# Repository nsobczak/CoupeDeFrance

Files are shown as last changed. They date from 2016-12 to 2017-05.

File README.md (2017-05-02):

# Coupe de France de robotique

## Robot principal

Notre robot principal doit être capable de réaliser les modules suivants :

| Nom du module | Priorité |
|---|---|
|Ramassage de cylindres |Moyenne|
|Funny action |Haute|

## Robot secondaire

Nous n'avons pas de robot secondaire. Si nous en avions un, il se chargerait du module suivant :

| Nom du module | Priorité |
|---|---|
|Ramassage de boules |Basse|

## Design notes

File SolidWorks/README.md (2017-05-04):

# SolidWorks

Pour ouvrir les assemblages :

-> Pour le mécanisme avec la pince :
El padre\isen2016-2017\SUPPORT DU MILIEU.SLDASM
-> Pour les mécanismes sur le robot :
El padre\Base roulante\Base du robot\Base_grand_robot_V3.SLDASM
-> Pour la funny action :
El padre\ Pince \ assemblage canon.SLDASM

Nb : Tous les éléments sont à l'echelle y compris le robot. Le robot a été agrandi pour la coupe de
	france de 2017 grace à des plaques visibles et équerres de fixation.
		Si vous avez des questions sur l'assemblage posez les à : olivier.jombart@isen.yncrea.fr
			Désolé pour le nommage de certaines pièces....

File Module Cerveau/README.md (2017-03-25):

# Module cerveau

Il s'agit du dossier contenant tout ce qui concerne le cerveau du robot : écran, software, harware...
Ce dossier contient aussi les dossiers communs à tous les modules, comme l'i2c par exemple.

## Dossiers propres au cerveau

- "Artificial Intelligence" est le dossier dans lequel est conservé ce qui concerne l'intelligence artificielle du robot.
- "Ecran" est le dossier dans lequel est conservé ce qui concerne l'écran.
- "ShieldCerveau" est le dossier contenant le harware du shield de la carte du cerveau.

## Dossiers communs aux différents modules

- "I2C" est le dossier contenant notre bibliothèque i2c et tests.

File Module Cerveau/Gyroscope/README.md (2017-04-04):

# Gyroscope/Accelerometre

Ce dossier contient les codes de tests de notre Gyroscope/Accelerometre.

Des information sur son utilisation peuvent être trouvée ici : https://knowledge.parcours-performance.com/ajouter-gyroscope-a-robot-arduino/

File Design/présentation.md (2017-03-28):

# notes

- chatterton
- plaque de plexi
- barre de led + fixation (4*7cm)
- adobe indesign

vendredi 31/03 : 11h-15h

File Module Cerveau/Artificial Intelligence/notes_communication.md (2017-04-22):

# Notes de communication

## 1. Notes I2C

- envois sur adresse paire
- réceptions sur adresse impaire

### Capteurs

I2C de la carte capteur => carte mère  (adresse 11):
- envoi des valeurs des capteurs ir et us (5 + 4 = 9 fois (10 s'ils fonctionnent tous))

### Gyroscope

Gyro => carte mère (adresse 68/69):
- envoi angle pour le connaître en temps réel (1 donnée: angle selon z)

### Carte mère

carte mère => carte asservissement (adresse 6):
- envoi angle pour stopper rotation quand angle est bien
- envoi ordre de déplacement du robot avec distance et vitesse: 1er octet correspond à l'ordre, 2ème à la partie entière de la consigne de distance, 3ème à la partie entière de la consigne de distance, 4ème à la partie entière de la consigne de vitesse, 5ème octet correspond à la partie décimale

carte mère => pince (adresse 8):
- envoi ordre à déclencher (y'en a 3)

## 2. Notes SPI

### Ecran

ecran => carte mère (adresse 13 ):
- envoi de la stratégie
- envoi de la couleur

## 3. Autre

### funny action

funny action :
- carte mère envoie un état haut à la nano qui commence à compter 90" et déclenche la funny action à la fin

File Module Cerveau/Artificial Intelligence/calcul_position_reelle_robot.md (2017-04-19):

# Calcul de la position réelle du robot

Le calcul de la position réelle est à réaliser en même temps que celui de l'asservissement en vitesse.

## Données

Nous disposons des données suivantes :

- ticks des codeuses
- distance séparant les 2 codeuses: voie
- nombre de ticks par tour de roue
- périmètre d'une roue codeuse

A partir du nombre de ticks, on calcule la distance réelle parcourue par le robot.

On place l'origine de l'axe x,y en bas à gauche du plateau. On place le plateau comme dans l'image ci-après, avec la zone de départ bleue placée en haut à gauche.<br>
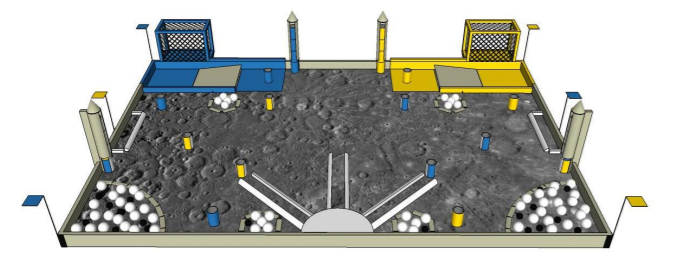
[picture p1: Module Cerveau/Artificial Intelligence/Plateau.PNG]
Plateau
<br>
L'axe y est dirigé vers la zone de départ bleue. L'axe x est dirigé vers le coin cratère de minerai jaune.

## Equations

Donnée                           | Nom de la variable
-------------------------------- | ------------------
Angle effectué en radian         | a
Distance parcourue               | d
Distance parcourue selon l'axe x | x
Distance parcourue selon l'axe y | y

- d = (ticks/nombre_ticks_par_tour_de_roue)\*perimetre_roue_codeuse
- en cas de rotation, a = voie/d
- x = d*cos(a)
- y = d*sin(a)

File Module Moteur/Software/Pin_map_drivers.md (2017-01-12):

# Pin Map Shield Moteur

# Drivermoteur gauche :
pwm - 6
IN1 - 52
IN2 - 53

# Drivermoteur Droit :
pwm - 3
IN1 - 22
IN2 - 23

# Encoder Gauche :
pinA - 13
pinB - 12

# Encoder Droit : 
pinA - 11
pinB - 10

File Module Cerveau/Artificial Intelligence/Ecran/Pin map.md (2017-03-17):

# Pin map de l'écran de controle

Les numéros correspondent aux pins de l'arduino mega.

## EXP1
----------------
|  |51|13|  |GND|  2 digital pin ,14 digital pin , 51 MOSI pin, 13 digital pin 
---------------- 
|02|14|  |  |5V|
----------------
      ----

## EXP2
----------------
|  |52|50|  |  |
----------------
|  |  |  |  |  |
----------------
      ----

----------------
|  |  |  |  |  |
----------------
|  |  |  |  |  |
----------------
      ----

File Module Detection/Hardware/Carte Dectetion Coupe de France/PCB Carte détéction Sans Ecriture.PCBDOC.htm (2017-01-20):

Reporting Options

# File in Previous Format

Date | : | 20/01/2017
Time | : | 09:35:36
Filename | : | C:\Users\ISEN\Documents\CoupeDeFrance\Module Dectetion\Hardware\Carte Dectetion Coupe de France\PCB Carte détéction Sans Ecriture.PCBDOC

Version | Warning

This file was generated by an earlier version of the software

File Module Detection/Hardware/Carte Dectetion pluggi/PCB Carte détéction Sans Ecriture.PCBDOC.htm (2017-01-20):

Reporting Options

# File in Previous Format

Date | : | 20/01/2017
Time | : | 09:43:30
Filename | : | C:\Users\ISEN\Documents\CoupeDeFrance\Module Dectetion\Hardware\Carte Dectetion pluggi\PCB Carte détéction Sans Ecriture.PCBDOC

Version | Warning

This file was generated by an earlier version of the software

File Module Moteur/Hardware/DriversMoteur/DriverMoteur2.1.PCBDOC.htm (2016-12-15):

Reporting Options

# File in Previous Format

Date | : | 09/12/2016
Time | : | 20:24:48
Filename | : | C:\Users\ISEN\Desktop\Projet coupe de France\Driver2.1\DriverMoteur2.1.PCBDOC

Version | Warning

This file was generated by an earlier version of the software

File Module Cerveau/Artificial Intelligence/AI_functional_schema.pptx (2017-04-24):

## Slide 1

Sens de lecture

El padre IA
Si tirette tirée

Fin du timer ?

Cylindre devant ?

Bouton d'arrêt d'urgence enclenché ?

Cylindre tenu ?

Adversaire présent ?

Aller vers la position théorique d'un cylindre de la liste

Cylindre tenu ?

Lâcher cynlindre

Dépôt de cylindre présent ?

Adversaire présent ?

Aller au dépôt

stopAll +
delay forever

Stop pendant un certain temps

Légende :

Condition

Action

Rammasser cylindre

Lâcher cylindre

Stop pendant un certain temps

Stop

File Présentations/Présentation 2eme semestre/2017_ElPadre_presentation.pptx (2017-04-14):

## El Padre

El Padre

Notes: Commentaire

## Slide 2

1.Intro

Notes: Commentaire

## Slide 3

1.1-Contexte

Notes: Commentaire

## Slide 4

1.2-Objectif

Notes: Commentaire

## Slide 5

1.3-Présentation équipe

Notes: Commentaire

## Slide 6

2.Présentation résultats

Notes: Commentaire

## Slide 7

3.Organisation

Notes: Commentaire

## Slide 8

4.Partie technique

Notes: Commentaire

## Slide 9

4.1-Intelligence artificielle

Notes: Commentaire

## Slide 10

4.1.1-Ecran

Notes: Commentaire

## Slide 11

4.1.2-Communication I2C/SPI

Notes: Commentaire

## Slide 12

4.1.3-Gyroscope

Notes: Commentaire

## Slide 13

4.1.4-Capteurs

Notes: Commentaire

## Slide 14

4.2-Asservissement

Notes: Commentaire

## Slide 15

4.2.1-Asservissement position

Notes: Commentaire

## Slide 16

4.2.2-Asservissement vitesse

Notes: Commentaire

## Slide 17

4.2.3-Drivers moteurs

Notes: Commentaire

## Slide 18

4.3-Pince

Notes: Commentaire

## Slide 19

4.3.1-Mécanique

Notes: Commentaire

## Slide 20

4.3.2-Software

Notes: Commentaire

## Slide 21

4.3.3-Hardware

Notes: Commentaire

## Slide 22

4.4-Funny action

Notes: Commentaire

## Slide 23

4.4.1-Mécanique

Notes: Commentaire

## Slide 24

4.4.2-Hardware

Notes: Commentaire

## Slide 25

4.4.3-Software

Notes: Commentaire

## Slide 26

5.Conclusion

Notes: Commentaire

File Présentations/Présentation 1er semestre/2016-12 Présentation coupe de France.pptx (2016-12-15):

## Coupe de France de robotique

Coupe de France de robotique

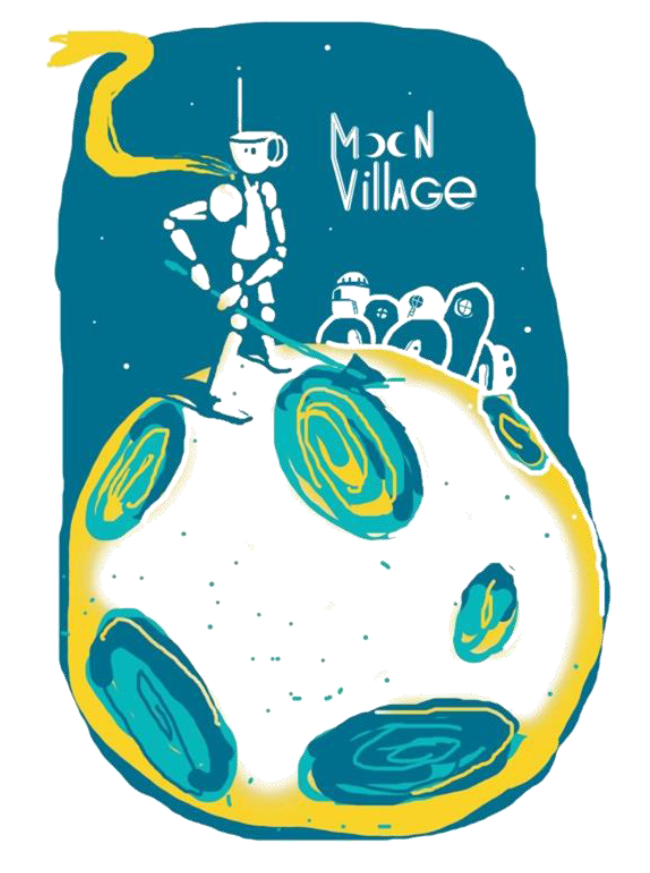
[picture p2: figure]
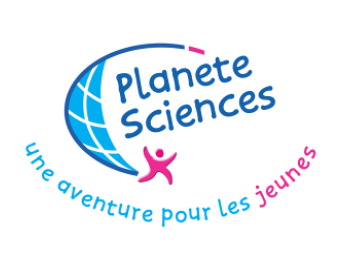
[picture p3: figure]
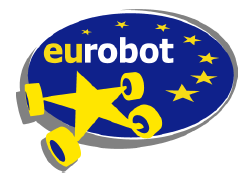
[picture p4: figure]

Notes: Commentaire

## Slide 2

Intro présentation de la coupe de France

Balles
Cylindres
Funny action
2 points par balle apportée dans la zone de départ
3 points par balle apportée dans le panier
10 points par cylindre apporté dans un rail
20 points si réalisée correctement
2 points par cylindre apporté dans la zone de départ

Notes: Commentaire

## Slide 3

Aire de jeu

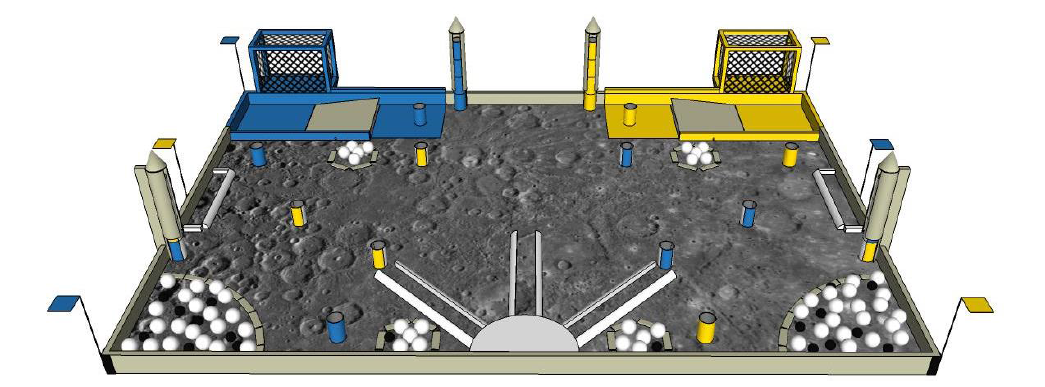
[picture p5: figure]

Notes: Commentaire

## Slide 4

Objectif du 1er semestre

Objectif du 1er semestre : faire rouler le robot

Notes: Commentaire

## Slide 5

Plan

I. Architecture du robot
II. L’écran
III. Les moteurs
IV. L’alimentation
V. Documentation

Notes: Commentaire

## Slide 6

I. L’architecture du robot

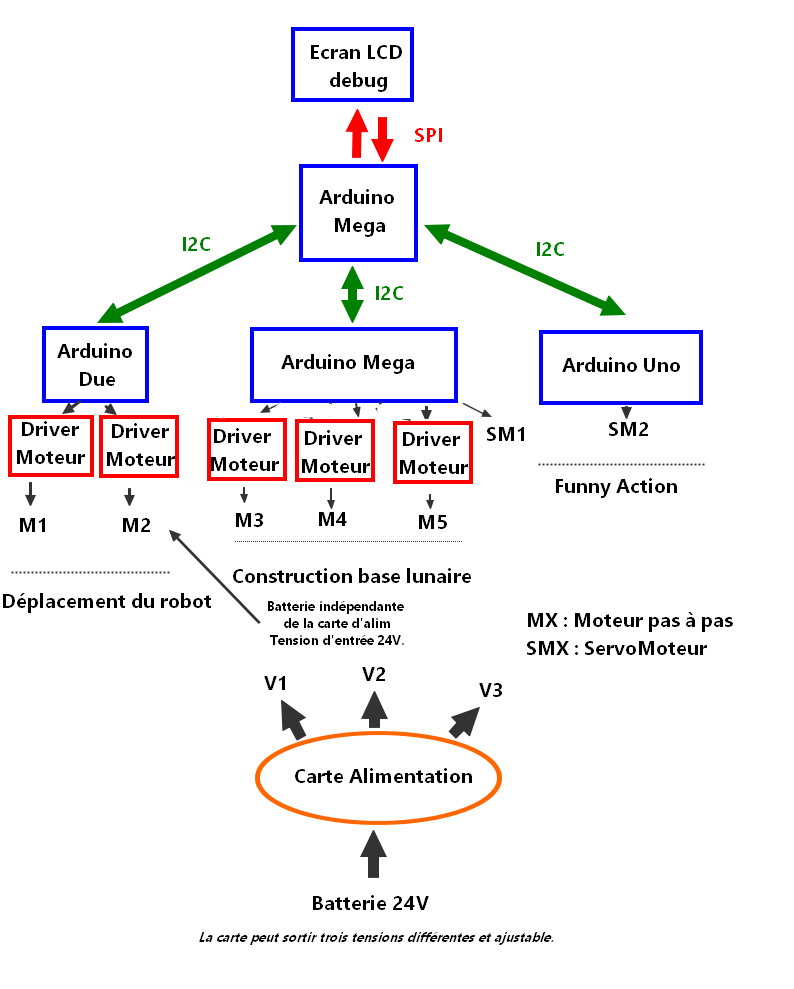
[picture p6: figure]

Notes: Commentaire

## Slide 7

II.1 L’écran

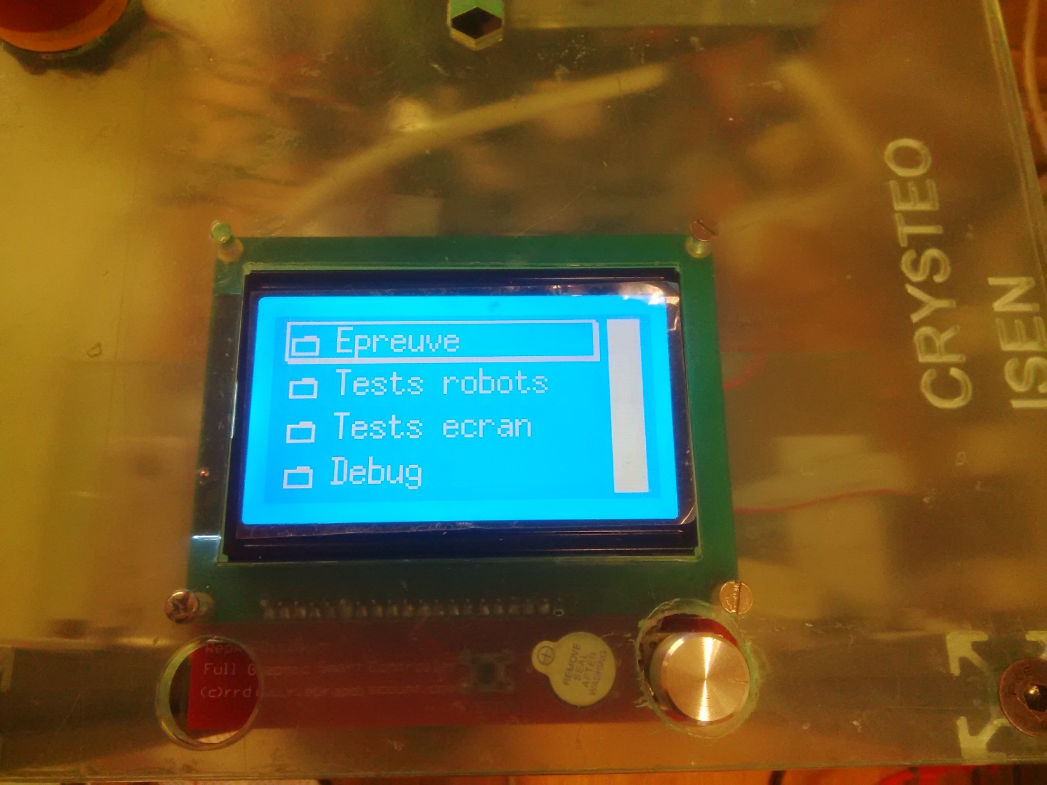
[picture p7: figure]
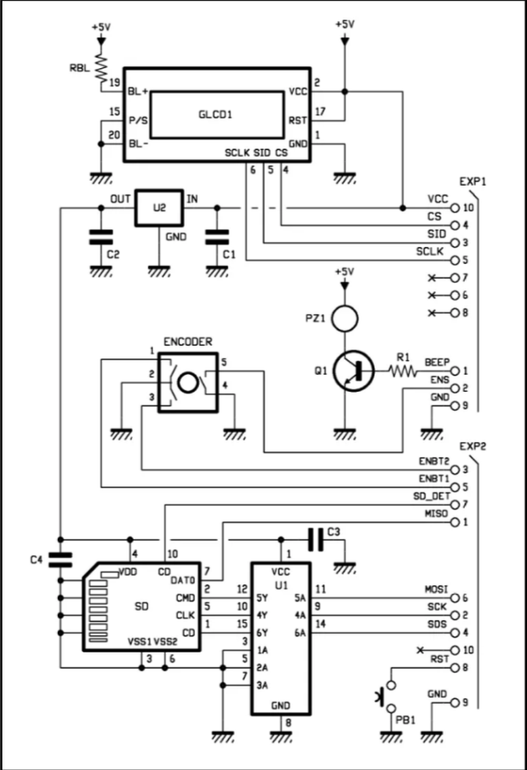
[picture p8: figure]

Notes: Ecran led - Encodeur qui a un bouton - Carte sd si besoin - Bouton poussoir
Intérêt = minimiser le nombre de boutons, choix de la stratégie, debug

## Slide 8

II.2 Les menus de l’écran actuel

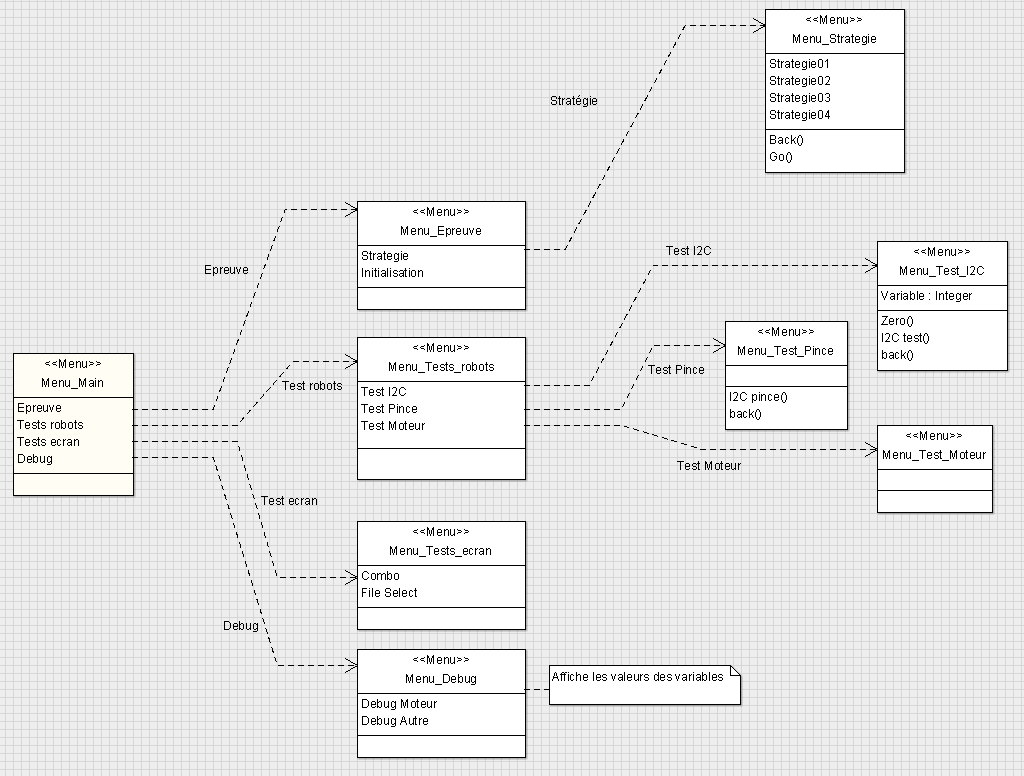
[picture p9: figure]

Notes: Gérer par une arduino mega. L’arduino mega = 7V. Ecran = 5V.
Communication entre les 2 = SPI
Programmation = biblio pour gérer l’écran et une pour gérer les menus
Démonstration de l’écran après si vous voulez

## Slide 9

III. Les moteurs

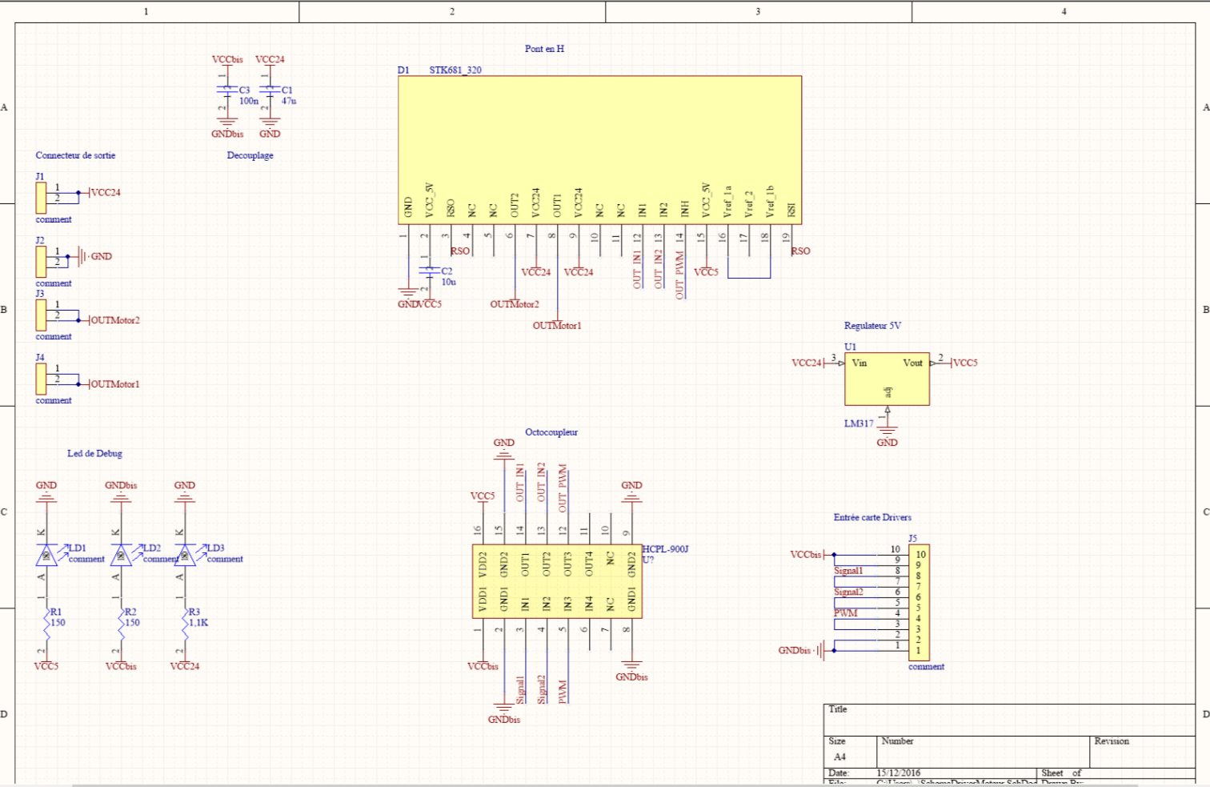
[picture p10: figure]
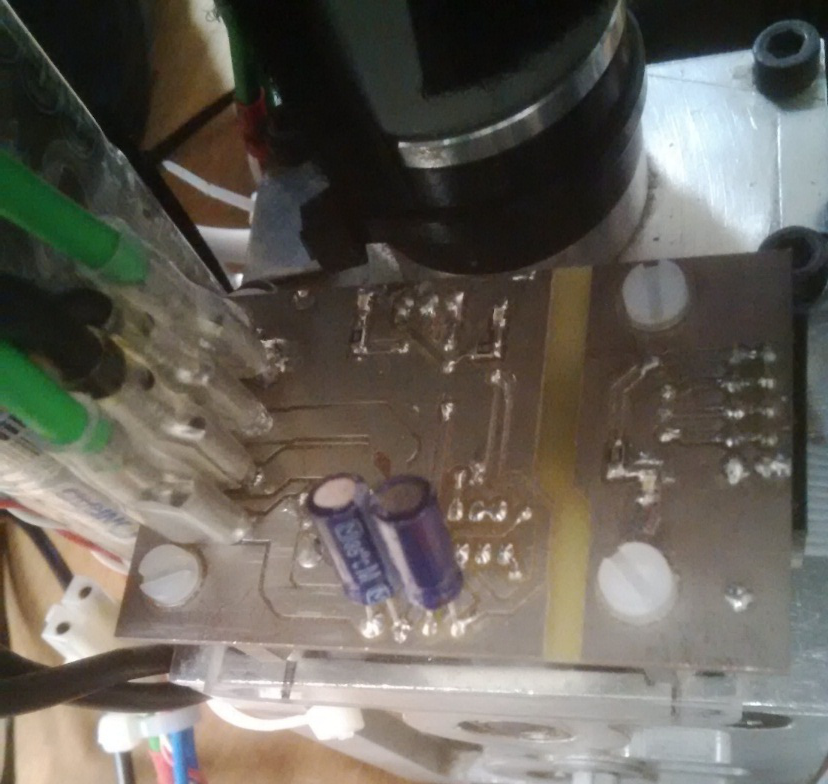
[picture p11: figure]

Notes: Commentaire

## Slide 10

IV. L’alimentation

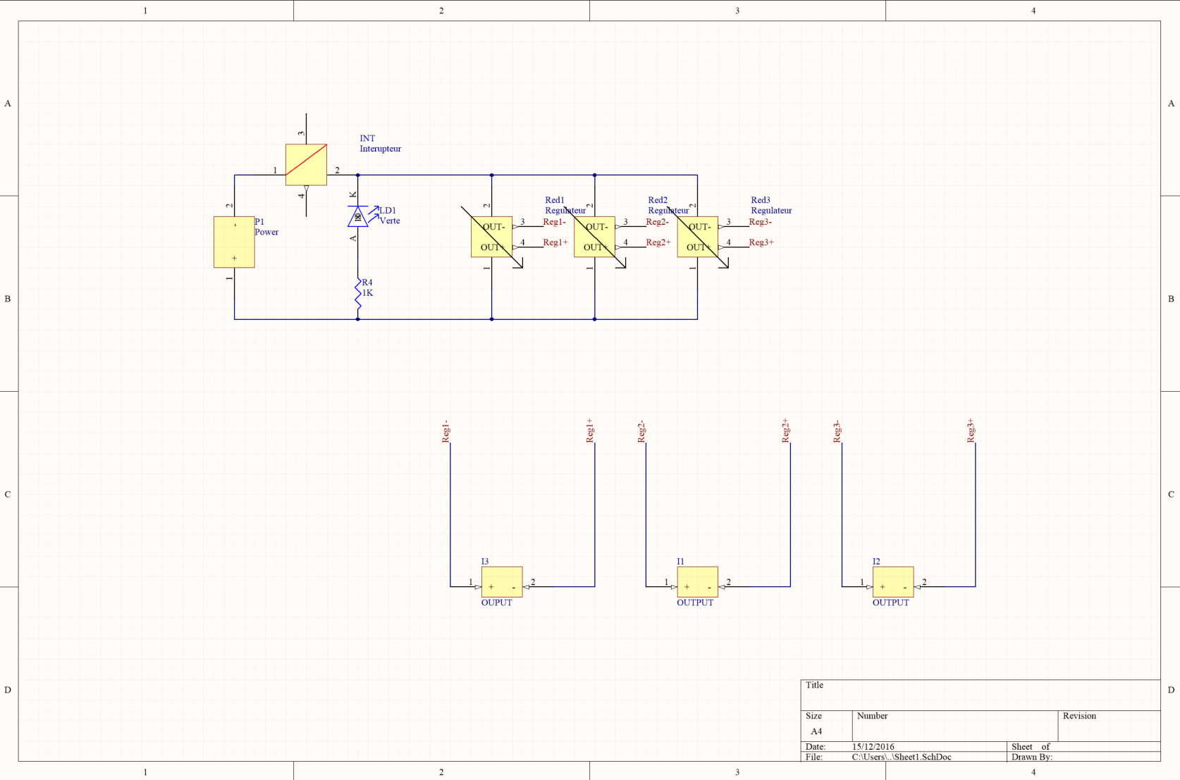
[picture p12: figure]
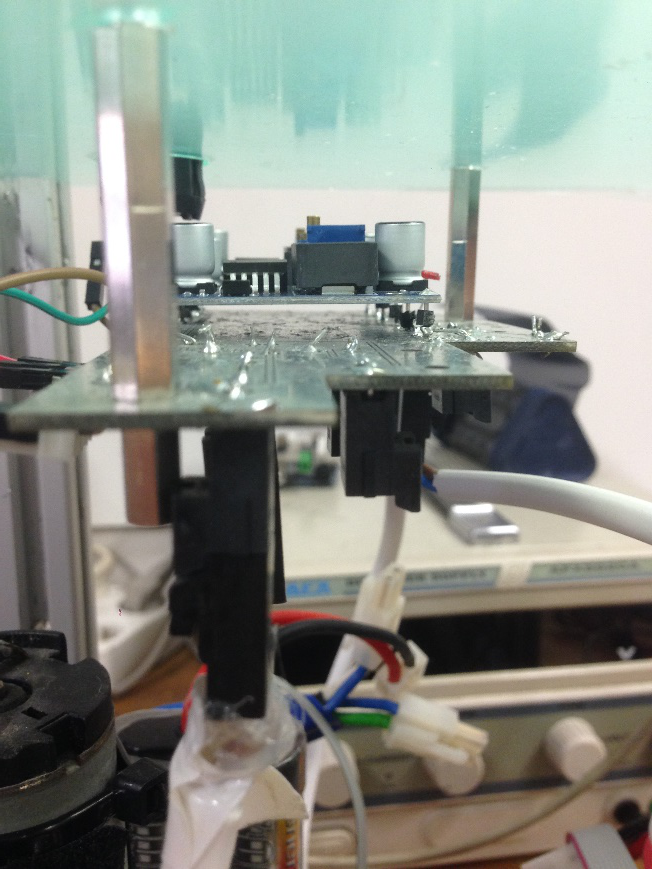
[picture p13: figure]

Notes: - Régulateur de tension basé sur principe d’alim à découpage

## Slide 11

V. Documentation

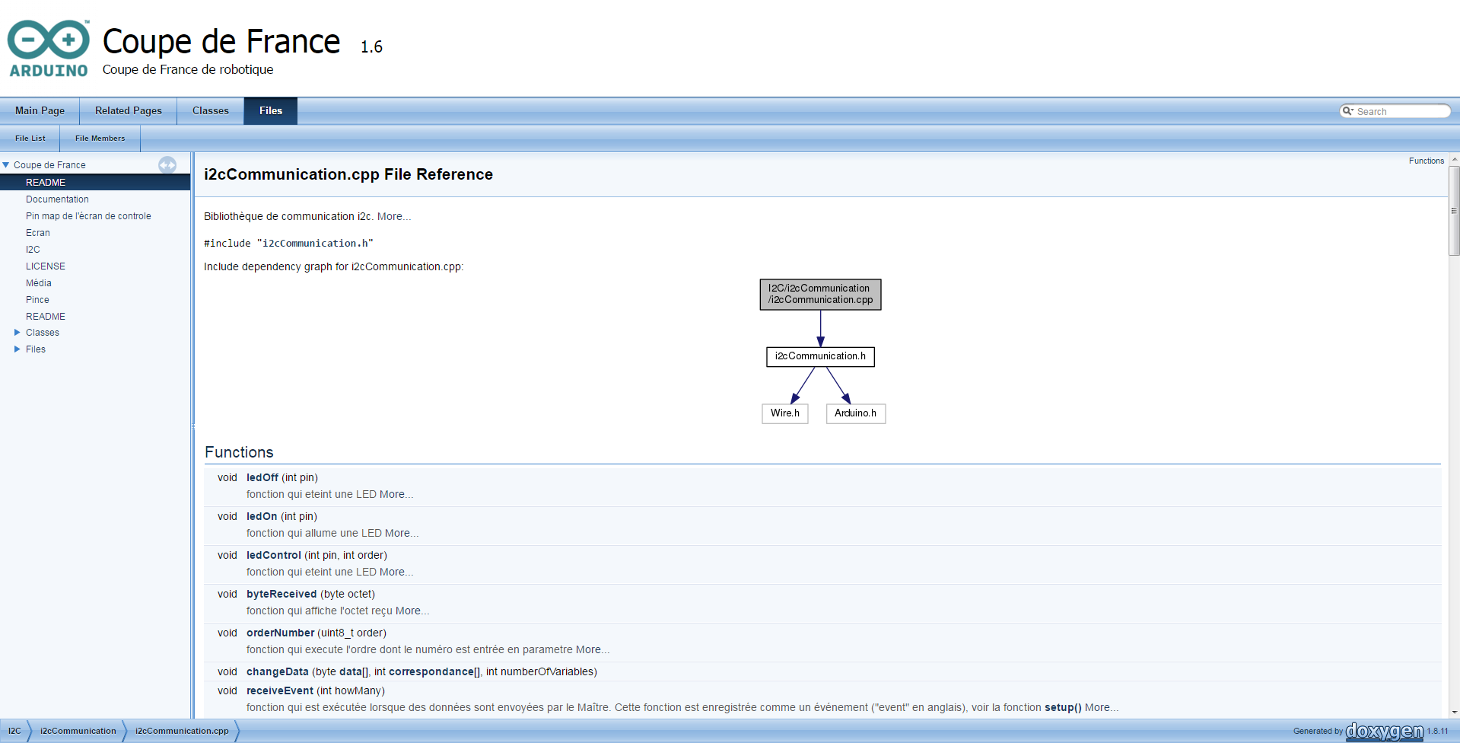
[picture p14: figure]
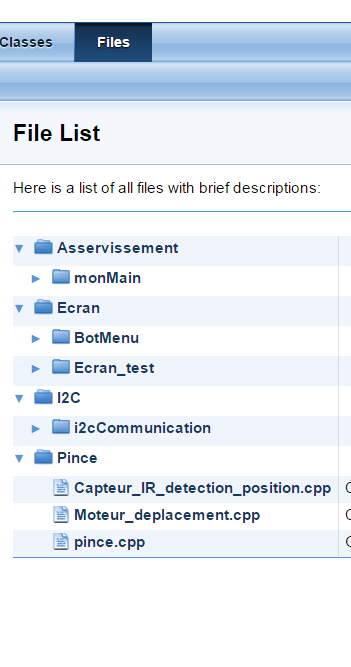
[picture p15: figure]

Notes: - Robot le plus réutilisable possible
- Mise en place de documentation => on commente le code (Doxygen), schéma élctrique, pin map…
- On utilise github pour sauvegarder tous nos fichiers => vous pouvez aller voir
- Au début on est parti sur des choses simples => maintenant on utilise les tag de c++ pour générer documentation

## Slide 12

V. Documentation

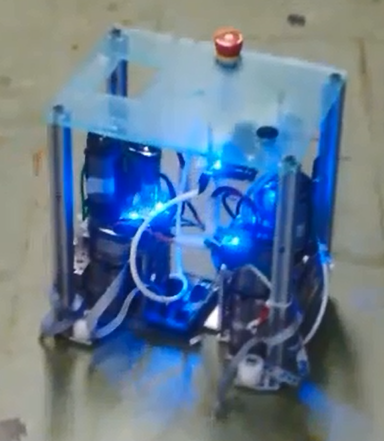
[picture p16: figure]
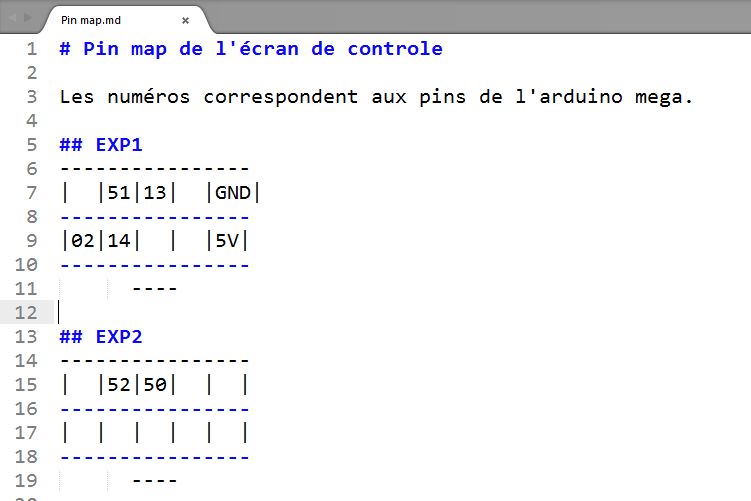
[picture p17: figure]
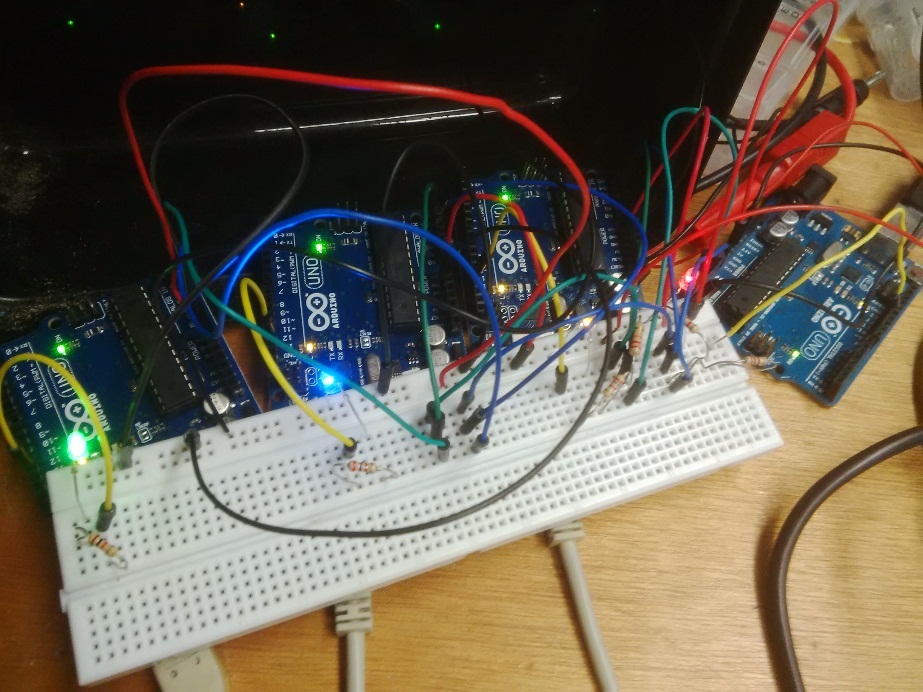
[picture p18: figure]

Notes: - Mise en place d’automatisme de documentation
- Prise de photos et vidéos

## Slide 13

Démonstration

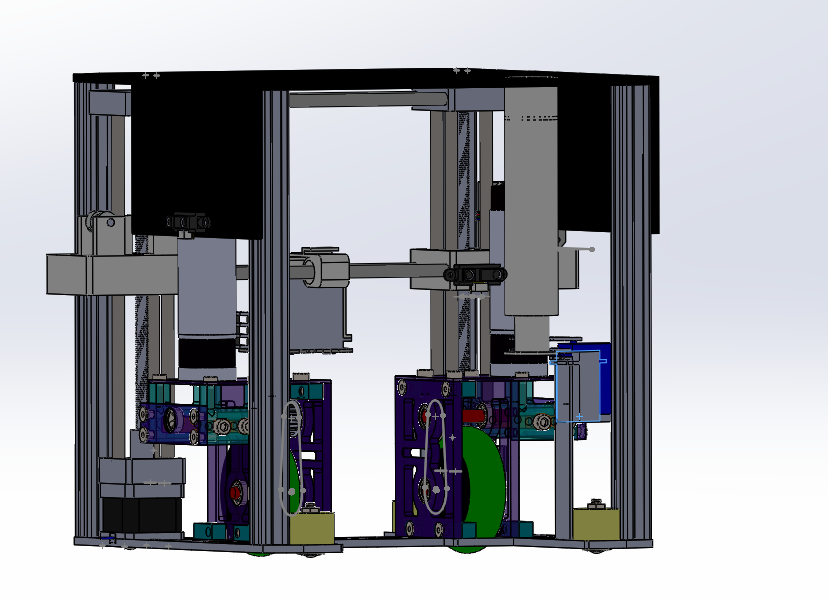
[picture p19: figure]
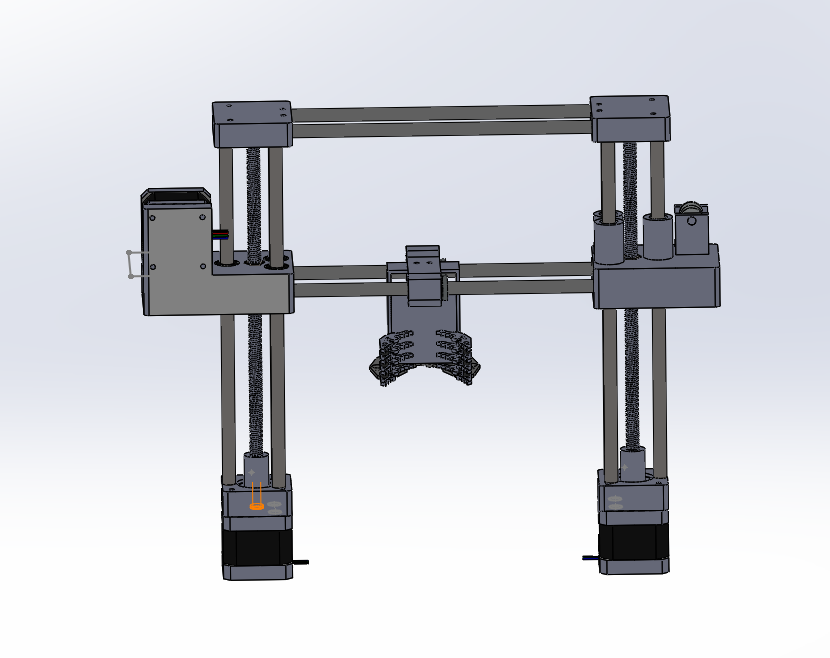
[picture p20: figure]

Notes: Commentaire

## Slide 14

Conclusion

Notre objectif est rempli
Il nous reste encore la partie actionneur à faire
Il nous faudrait plus de monde

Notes: Commentaire

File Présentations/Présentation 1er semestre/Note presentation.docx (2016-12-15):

Arthur
Nicolas
Olivier

# Intro

Expliquer coupe France + épreuves + point

Mentionner nos objectifs pour 1 semestre + objectif final

# 1. Expliquer l’architecture du robot

1 microcontrôleur par module -> Car si un crash les autres ne sont pas impactées

Donc 3 microcontrôleur pour chaque épreuve.

Plus 1 microcontrôleur pour gère le tout (faire le cerveau)

Plus 1 microcontrôleur pour gérer les moteurs (déplacement du robot)

Communication en I2C création de notre propre bibliothèque

# 2. Module Ecran

Ecran LED + encoder (possibilité d’utilisation d’une carte SD + bouton poussoir)

Intérêt : Debug, Choix stratégie, enlever tous les boutons

Gérer par la carte maître alimentée (Arduino Méga)

Tension d’alimentation : 7V Arduino Méga 5V Ecran

Communication : Ecran Arduino SPI

Programmation : utilisation bibliothèques

# 3. Moteur

Moteur 24V 2 A

Schéma électrique

Entrée : 3 signaux logique (IN1 IN2 PWM) 3.3V

Sortie : PWM 24V 1 à 2 A

Optocoupleur : isolation des masses et des signaux

Pont en H : Gere la puissance et le sens du moteur se met en sécurité à partir de 8A (réglable)

Régulateur 5V : fournie niveaux logiques au pont en H et alimente optocoupleur

Finie et opérationnel !!

Arduino Due fonctionnement 89 Mhz -> Car fréquence d’envoie des ticks importante

Alimentation 7V

Gere l’asservissement niveau documentation

# 4. Alimentation

Carte primordiale du robot-> opérationnel rapidement

Carte d’alimentation provisoire sortie 3 tension réglable 1 A Max tension d’entrée 24V

7V->Arduino, 5V-> Driver Moteur, Ecran 12V-> Moteur pas à pas

Amélioration au second semestre 5A Max 3 tension sortie amélioration

Capa découplage, Largeur des piste, connecteur, éventuellement fusible

# 5. Documentation

Robot le plus réutilisable possible

Mise en place d’automatisme de documentation

Prise de photo et vidéo, code commenter

Mise en place d’outil de partage et documentation

GitHub :

Partie hardware Partie software

(107 sauvegarde)

Documentation automatique

DOXYGEN v1.8.11

Nous sommes actuellement à la version v1.6 de la documentation

# Conclusion

- Dire objectif rempli + ce qu’on compte faire + finir sur les ressources

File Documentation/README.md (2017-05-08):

# Documentation

Ce dossier est destiné à acceuillir tout ce qui concerne la documentation.
Pour visualiser la documentation, il faut lancer le fichier html/index.html

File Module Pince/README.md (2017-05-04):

## Moteur_deplacement

Dossier contenant le fichier du code pour lancer les moteurs de déplacement de la pince.

## Tests

Dossier de tests.
---Inutile---

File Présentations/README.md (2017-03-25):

# Présentation

Dossier contenant les différentes présentations.

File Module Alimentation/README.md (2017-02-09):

# Module Alimentation

Il s'agit du dossier contenant le hardware de la carte d'alimentation.

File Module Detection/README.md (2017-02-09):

# Module Détection

Dossier contenant le hardware et le software du module de détection.

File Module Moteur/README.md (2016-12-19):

# Module moteur

Il s'agit du dossier destiné à accueillir tout ce qui concerne la carte les moteurs servant à faire rouler le robot.

## Description des dossiers

Ce dossier est composé de 2 sous-dossiers :

- Hardware : dossier contenant toute la partie hardware des moteurs, comme la carte driver par exemple.
- Software : dossier contenant toute la partie sorftware des moteurs, comme l'asservissement par exemple.

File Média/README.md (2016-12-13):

# Média

Dossier contenant les vidéos et photos de notre projet.

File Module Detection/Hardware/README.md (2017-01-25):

# Hardware

## Carte détection coupe de France

Carte de détection du robot de la coupe de France.

## Carte détection pluggi

Carte depuis laquelle nous partons pour réaliser la carte de détection du robot de la coupe de France.

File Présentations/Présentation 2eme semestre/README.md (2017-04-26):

# Présentation 2eme semestre

Dossier contenant les fichiers ayant servi pour notre présentation du 2eme semestre.

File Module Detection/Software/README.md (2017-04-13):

# Software

## CoupeDeFranceDetectionv2.0

Code de la carte de détection du robot de la coupe de France.

## MainDetectionPluggi

Code de la carte depuis laquelle nous partons pour réaliser la carte de détection du robot de la coupe de France.

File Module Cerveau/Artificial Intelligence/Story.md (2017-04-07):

# Bot AI Story

## TODO

### Généralités

- aller ramasser et placer les cylindres
- éventuellement s'occuper du ramassage de balles
- funny action
- utiliser un timer pour vérifier si l'épreuve est finie ou pas

### Notes techniques

- faire une classe Bot qui aura toutes les fonctions du robot
- penser à prévoir des manoeuvres/actions spéciales en cas de bug (robot coincé dans un coin par exemple)
- prévoir la liste des positions théoriques des cylindres
- prévoir la liste des positions théoriques des emplacements où placer les cylindres

## 1\. Départ

On sélectionne le programme avec l'écran puis on tire la tirette.

- si on détecte que la tirette est tirée => on lance le programme
- le programme écrit un état haut dans la nano qui déclenche le timer de la funny action (à la fin des 90", on lance la funny action)
- le programme lance un timer + déplacement vers un cylindre

## 2\. Déplacement (cylindres + boules)

On se déplace vers une position théorique du cylindre.

- si c'est la fin des 90" - le temps de lâcher un cylindre,

  - si on a un cylindre, on le lâche
  - dans tous les cas, on s'arrête

- sinon

  - on corrige avec l'asservissement
  - si on détecte l'adversaire => manoeuvre d'évitement
  - si on détecte un cylindre => on le ramasse

### 2.1 Eviter l'adversaire

**TODO:** Il faut décider de quelle manière on va réagir :

- on l'attaque en lui tirant dessus ou en faisant la toupies à fond par exemple
- on s'arrête en espérant qu'il finisse par bouger
- on s'arrête pendant un certain temps, puis on repars s'il n'est plus là (sinon on recommence l'action de s'arrêter)
- on l'évite en reculant ou partant n'importe où
- on regarde ce qu'il fait, où il va et on part de l'autre côté (ça peut être difficile, faut réussir à analyser où il va)

### 2.2 Détection cylindre

**NOTE:** On ne détecte que les cylindres qui sont debouts.

**TODO:** faire une liste des positions théoriques des cylindre que l'on cherche à ramasser.

- si on est proche de la position théorique d'un cylindre, on cherche un cylindre avec les capteurs pendant une certaine durée (**TODO: à déterminer**) et si capteur renvoie l'info de présence d'un cylindre => on a trouvé un cylindre \o/

  - on se déplace pour l'attraper
  - on lance une fonction du module pince : attraper + monter + tourner
  - on se déplace pour aller le placer à une position théorique
  - une fois qu'on est arrivé, on lance une fonction du module pince : (tourner) + descendre + lâcher
  - on va à une autre position théorique de cylindre

- sinon (si on dépasse la période et qu'on a pas détecté de cylindre), on va ramasser le cylindre suivant de la liste.

### 2.3 Détection minerai

**TODO:** Cherche-t-on à ramasser les minerais ?

## 3\. Funny action

- à la fin des 90", l'arduino nano lance la funny action avec une fonction

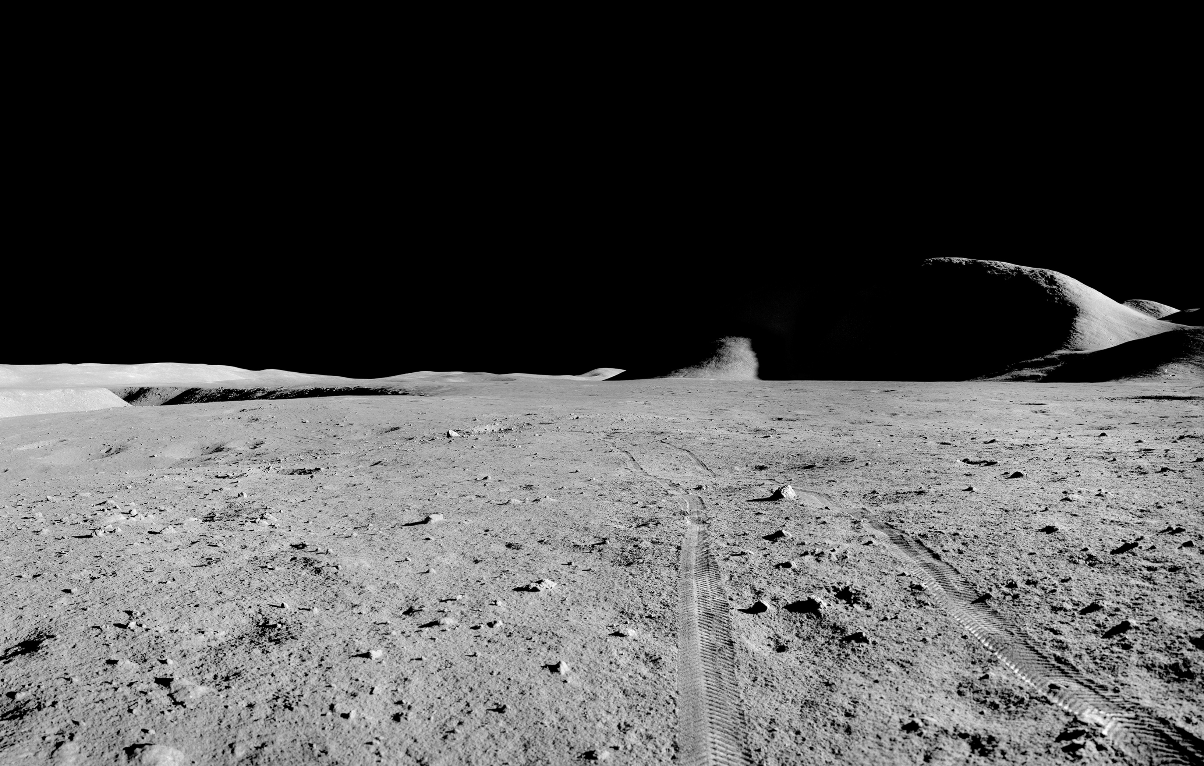
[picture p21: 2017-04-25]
Présentations/Présentation 2eme semestre/Poster/BACKGROUND.jpg

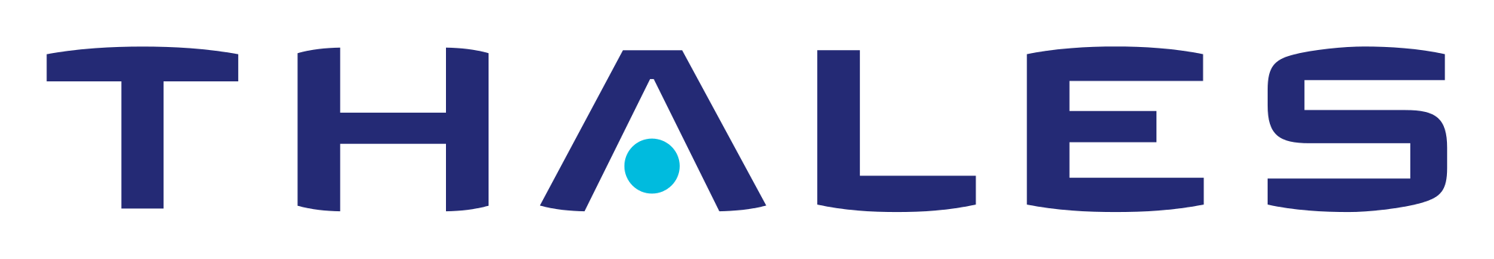
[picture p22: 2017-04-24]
Présentations/Présentation 2eme semestre/Poster/THALES.png

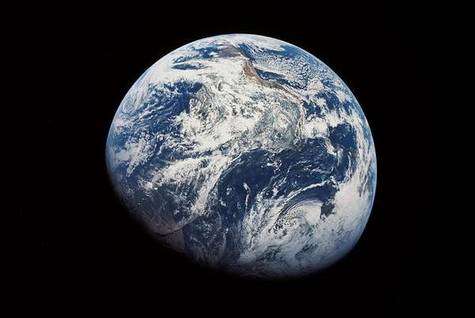
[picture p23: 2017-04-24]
Présentations/Présentation 2eme semestre/Poster/86aa8a48f0_50034785_terre-060307.jpg

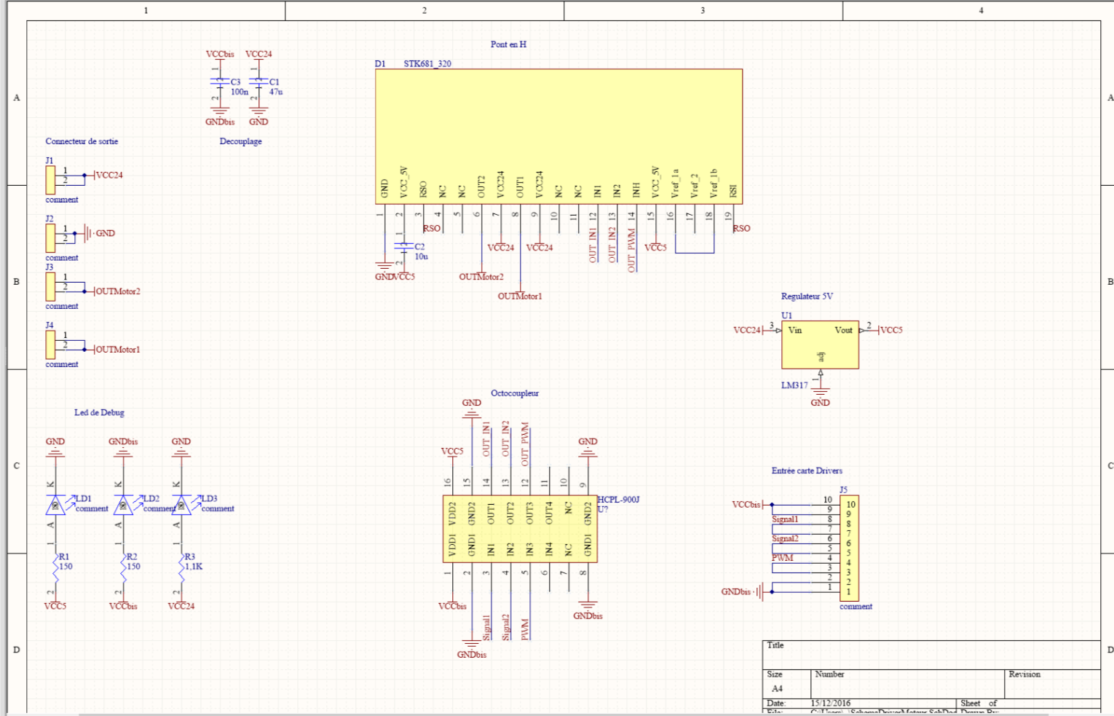
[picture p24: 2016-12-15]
Module Moteur/Hardware/DriversMoteur/Shematics.png

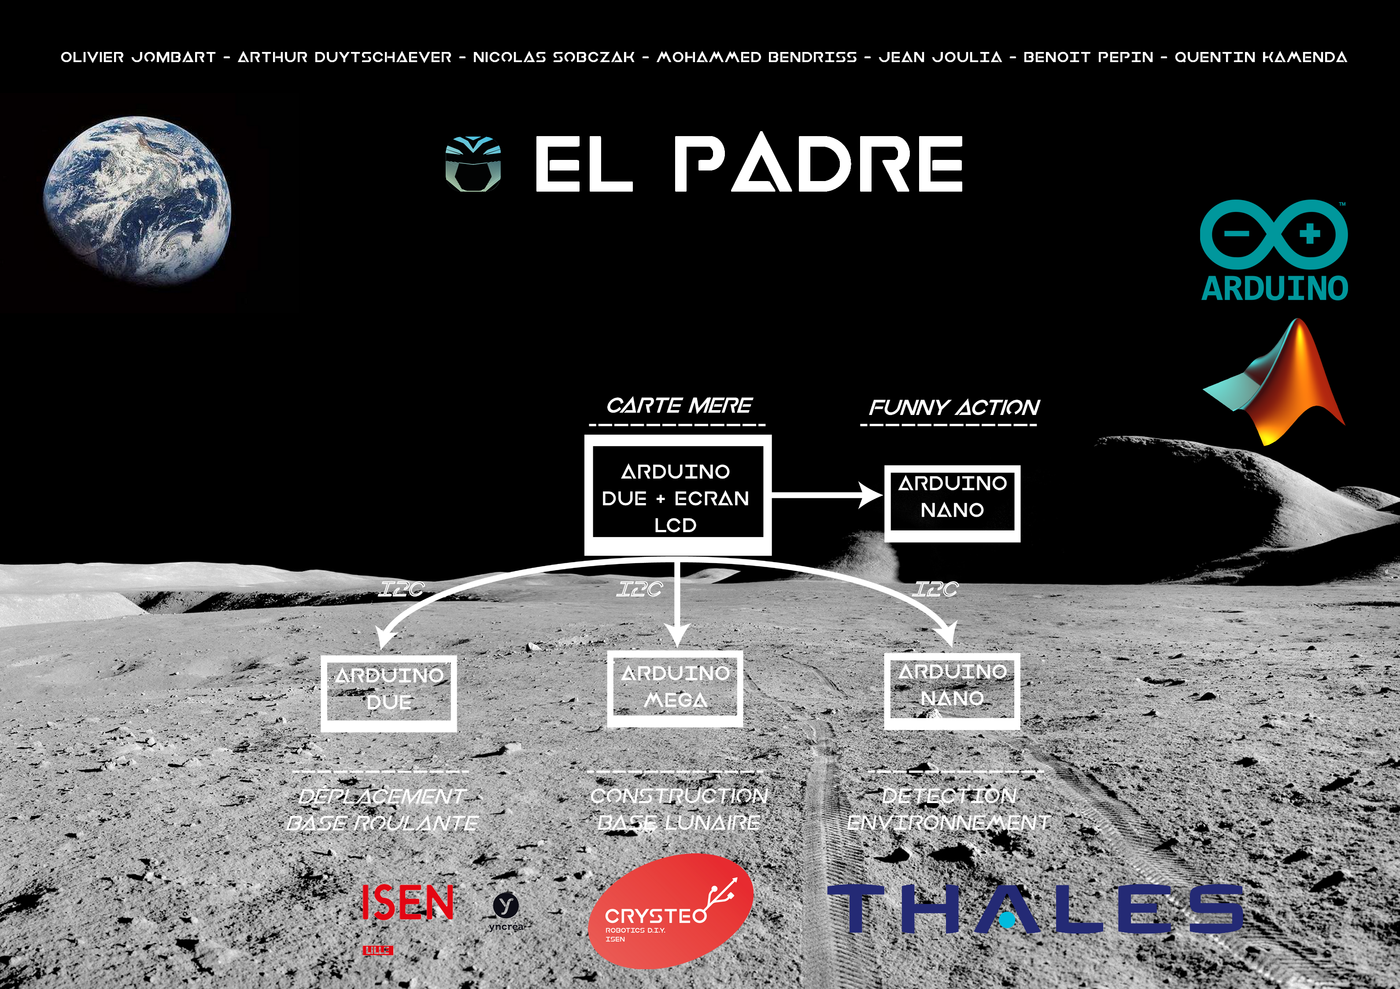
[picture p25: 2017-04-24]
Présentations/Présentation 2eme semestre/Poster/poster.png

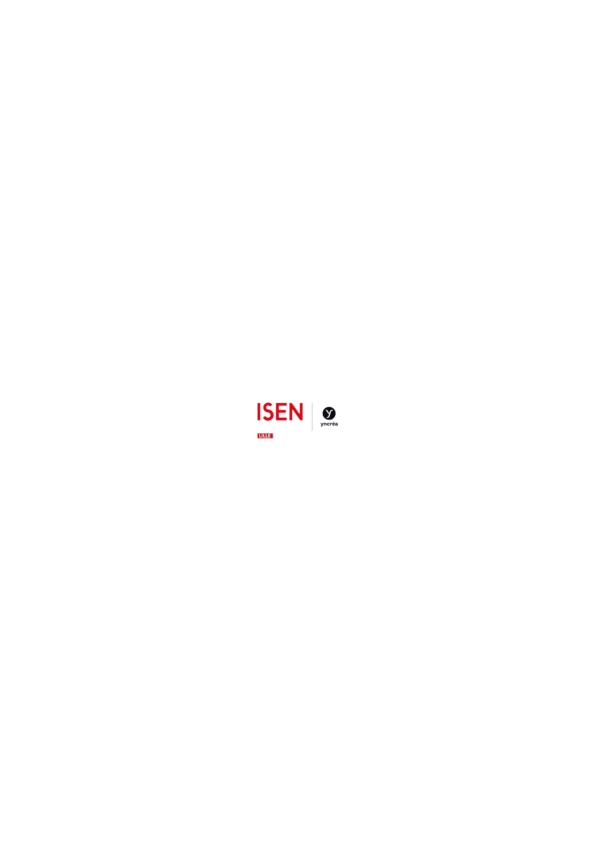
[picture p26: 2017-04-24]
Présentations/Présentation 2eme semestre/Poster/isen.png

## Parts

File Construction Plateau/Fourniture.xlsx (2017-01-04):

Caractéristique | Qté | Matériau | Prix UT | Prix Total* | Site vendeur**
Minerais (Shpère) 60mm (x60) | 3 | POLY | 6.50 € | 19.50 € | http://www.ebay.fr/itm/Lot-de-20-boules-polystyrene-Styropor-diam-6-cm-60mm-/131948207222
Roches Lunaires (Sphère) 40mm (x18) | 1 | POLY | 4.20 € | 4.20 € | https://www.stoklasa.fr/boule-en-polystyrene-37-40-mm-x127487?gclid=CJj9gvGrss8CFQVuGwody4QGfg
Champlat médium (MDF) 2 arrondis imitation chêne, 4 x 30 mm, L.2.4 m | 2 | MDF | 4.70 € | 9.40 € | http://www.leroymerlin.fr/v3/p/produits/champlat-medium-mdf-2-arrondis-imitation-chene-4-x-30-mm-l-2-4-m-e57428
Tube d'évacuation PVC, Diam.63 mm, L.4.1 m | 2 | PVC | 7.70 € | 15.40 € | http://www.leroymerlin.fr/v3/p/produits/tube-d-evacuation-pvc-diam-63-mm-l-2-m-e9935
Tube PVC non normé, Diam.80 mm L.4.1 m | 1 | PVC | 9.50 € | 9.50 € | http://www.leroymerlin.fr/v3/p/produits/tube-pvc-non-norme-diam-80-mm-l-4-m-e159468
Quart-de-rond sapin autoclave petits noeuds, 28 x 28 mm, L.2.4 m | 2 | Bois | 9.50 € | 19.00 € | http://www.leroymerlin.fr/v3/p/produits/quart-de-rond-sapin-autoclave-petits-noeuds-28-x-28-mm-l-2-4-m-e1400913670
Bombe peinture Jaune | 1 |  | 7.95 € | 7.95 € | http://www.leroymerlin.fr/v3/p/produits/peinture-aerosol-brillant-luxens-jaune-anis-n-4-0-4-l-e1400894225
Bombe peinture Bleue | 1 |  | 7.95 € | 7.95 € | http://www.leroymerlin.fr/v3/p/produits/peinture-aerosol-brillant-luxens-bleu-bleu-n-2-0-4-l-e1400894223
Bombe peinture Noir | 1 |  | 7.95 € | 7.95 € | http://www.leroymerlin.fr/v3/p/produits/peinture-aerosol-satin-luxens-noir-noir-n-0-0-4-l-e1400894194
Panneau contreplaqué ordinaire, Ep.5 mm x L.250 x l.122 cm | 2 |  | 15.47 € | 30.94 € | http://www.leroymerlin.fr/v3/p/produits/panneau-contreplaque-ordinaire-ep-5-mm-x-l-250-x-l-122-cm-e105080
Tasseau sapin petits noeuds raboté, 27 x 44 mm, L.2.4 m | 3 | Bois | 5.60 € | 16.80 € | http://www.leroymerlin.fr/v3/p/produits/tasseau-sapin-petits-noeuds-rabote-27-x-44-mm-l-2-4-m-e61975
tige pour la bascule
Panneau il faut 2x (350*360)mm (5mm d'épaisseur)
Visses à bois
Total |  |  |  | 124.89 €

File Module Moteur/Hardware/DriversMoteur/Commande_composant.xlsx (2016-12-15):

Bon de Commande
Nom des étudiants: |  | Arthur Duytschaever
N-poste | Fournisseur | Quantité | U.D.V | Désignation | Référence | Prix en €
1 | Farnell | 2 | 1 | STK681-360-E Motor Driver | 2424510 | 4.9
1 | Farnell | 2 | 1 | HCPL-090J-000E Isolateur numérique | 1611323 | 11.57
 |  |  |  |  | Total H.T. | 32.94

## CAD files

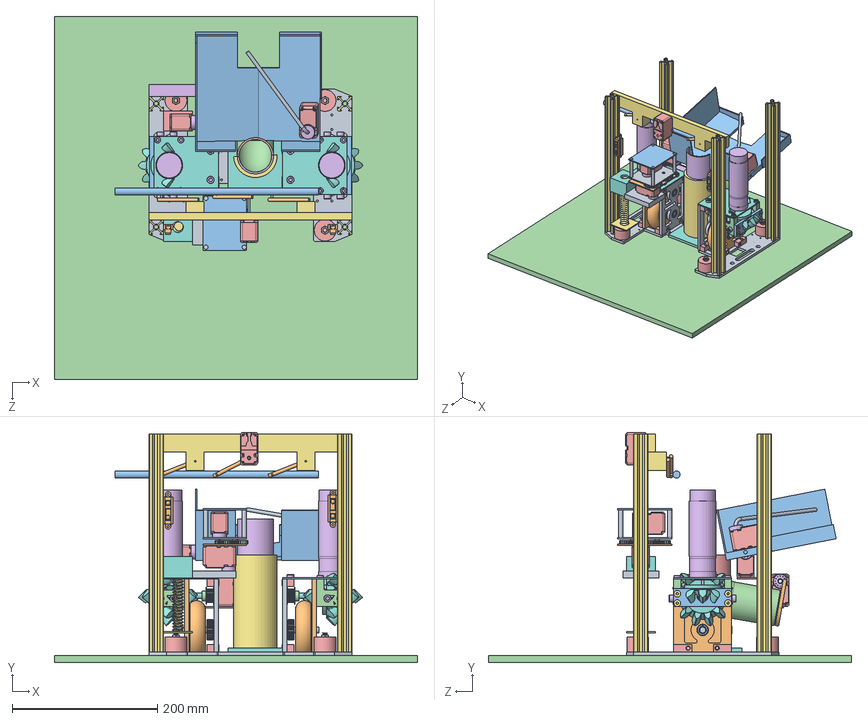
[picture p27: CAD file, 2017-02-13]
SolidWorks/El Padre/Base_roulante/Assemblage final/Base_grand_robot_V3.SLDASM
500.0 x 317.2 x 500.0 mm
base_v3
contour_roulement x 4
porte_bille x 4
bille x 4
Support_bille_appui x 4
hex thin nut chamfered gradeab_iso x 4
Profile20O6_V2 x 4
support moteur x 2
support central x 2
support inter x 2
support exter x 2
RENFORT x 4
fix carre x 6
moteur x 2
support coulisse x 4
axe inter x 2
axe roue x 2
roue x 2
angular contact ball bearing_68_iso x 10
poulie 20 dents x 2
poulie 30 dents x 2
socket head cap screw_iso x 20
socket countersunk head screw_iso x 18
straight miter gear_iso x 4
plaque_engrenage_avec_trou
plaque_engrenage_qui_sort
plaque_pivot_servo
spur gear_iso x 3
herkulex_DRS0101_servomoteur x 6
roulementHerkulex x 6
vis_sans_fin
support_pince_pour_vis
support_servomoteur
SharpIR x 2
Bac ping pong
tube2
Tube1
bord
Poutre
socle
tige
clapet1
clapet2
Gand socle
socle servo bac
socle servo clapet
support
Vis 1 x 3
Vis 2 x 3
tigeSupport x 3
tigeCLAP

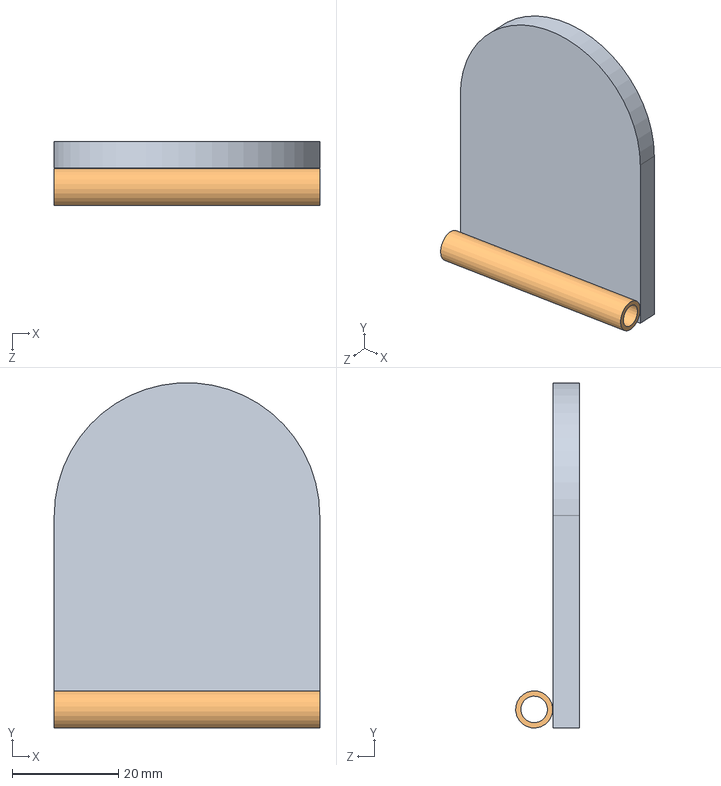
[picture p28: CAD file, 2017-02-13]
SolidWorks/El Padre/Base_roulante/Assemblage popcorn/Pièces/Clapet/clapet final.SLDASM
50.0 x 65.0 x 12.0 mm
clapet1
clapet2

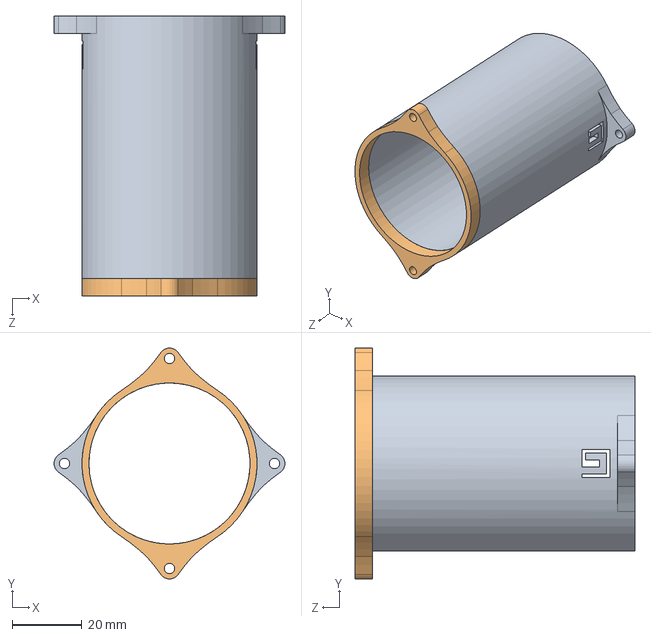
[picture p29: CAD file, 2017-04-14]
SolidWorks/El Padre/Base_roulante/cristeo/fixatio canon.SLDASM
66.0 x 66.0 x 80.0 mm
canon
bague support

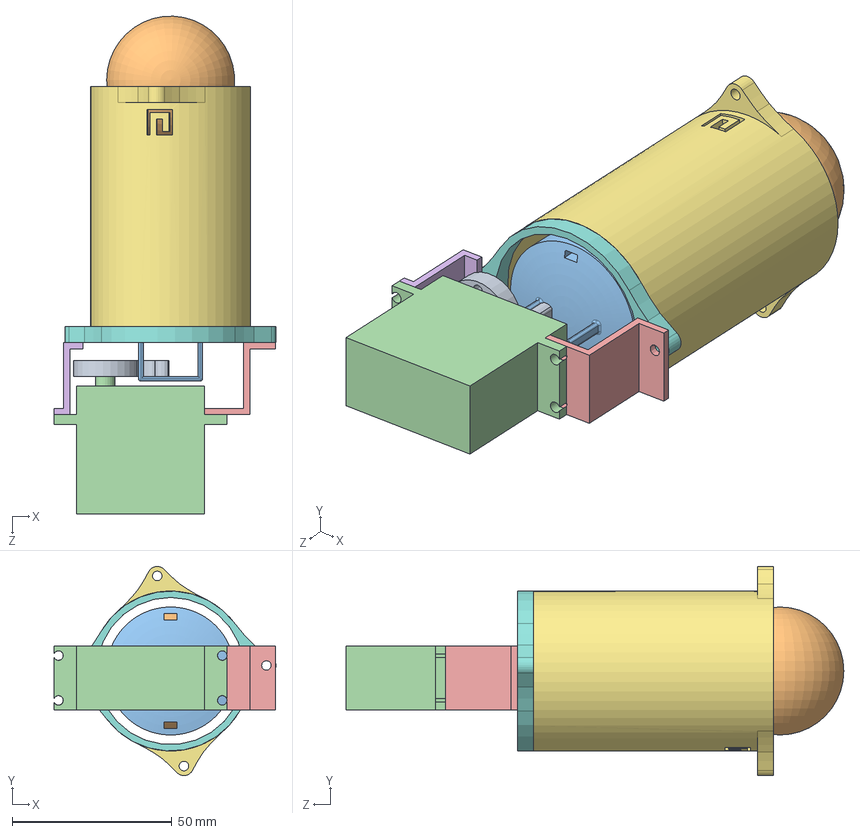
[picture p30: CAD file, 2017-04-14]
SolidWorks/El Padre/isen robot 2016-17/Funny Action/Assemblage canon 1.SLDASM
69.4 x 65.4 x 155.6 mm
acroche
la boule
lanceur
servo moteur
support moteur 2
support servo moteur 1
canon
bague support

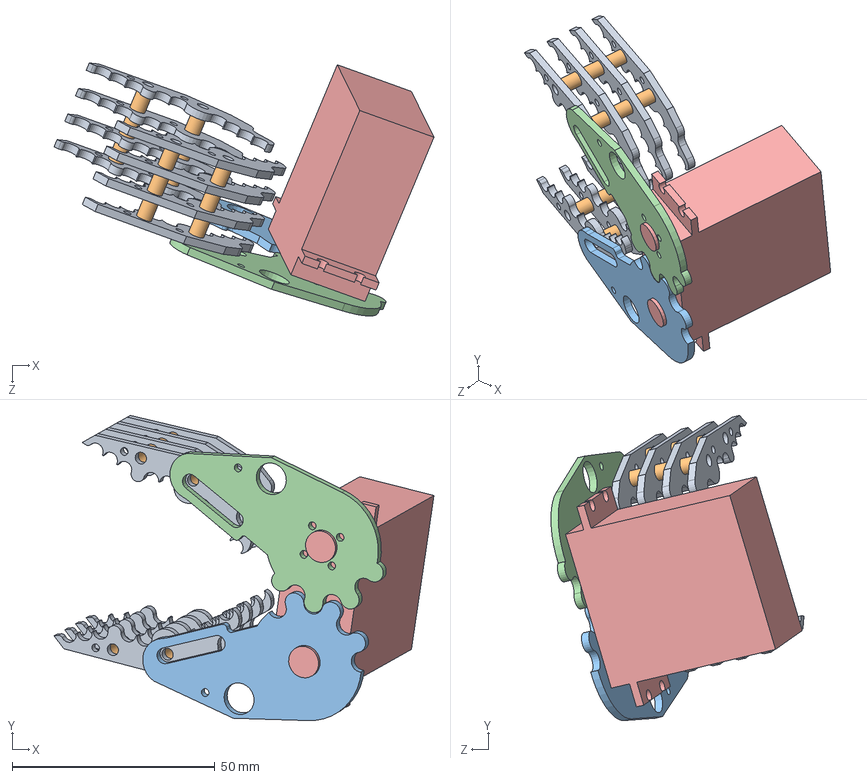
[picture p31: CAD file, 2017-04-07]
SolidWorks/El Padre/isen robot 2016-17/Pince/Assemblagepince.SLDASM
93.8 x 75.3 x 62.5 mm
piece pince x 8
Pièce2 x 12
Pièce4
Pièce3
Pièce5

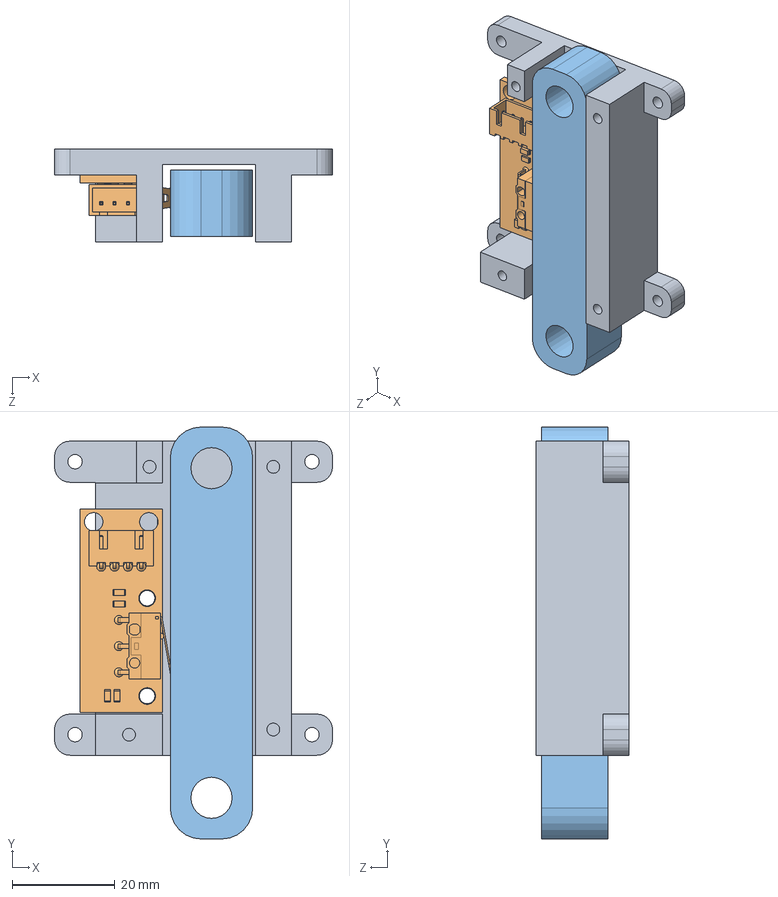
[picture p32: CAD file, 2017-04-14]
SolidWorks/El Padre/isen robot 2016-17/TiretteDeDepart/Tirettededepart.SLDASM
54.0 x 80.0 x 18.0 mm
Bas
End-Stop
Tirette

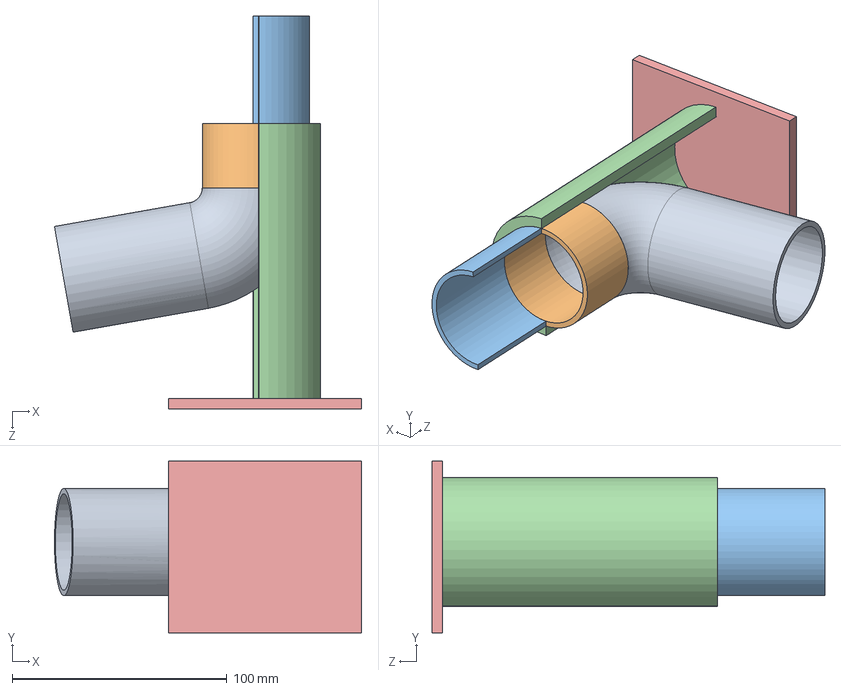
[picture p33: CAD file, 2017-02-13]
SolidWorks/El Padre/Base_roulante/Assemblage popcorn/Pièces/Tube/tube+bord.SLDASM
143.0 x 80.0 x 183.0 mm
tube2
Tube1
bord
Poutre
socle

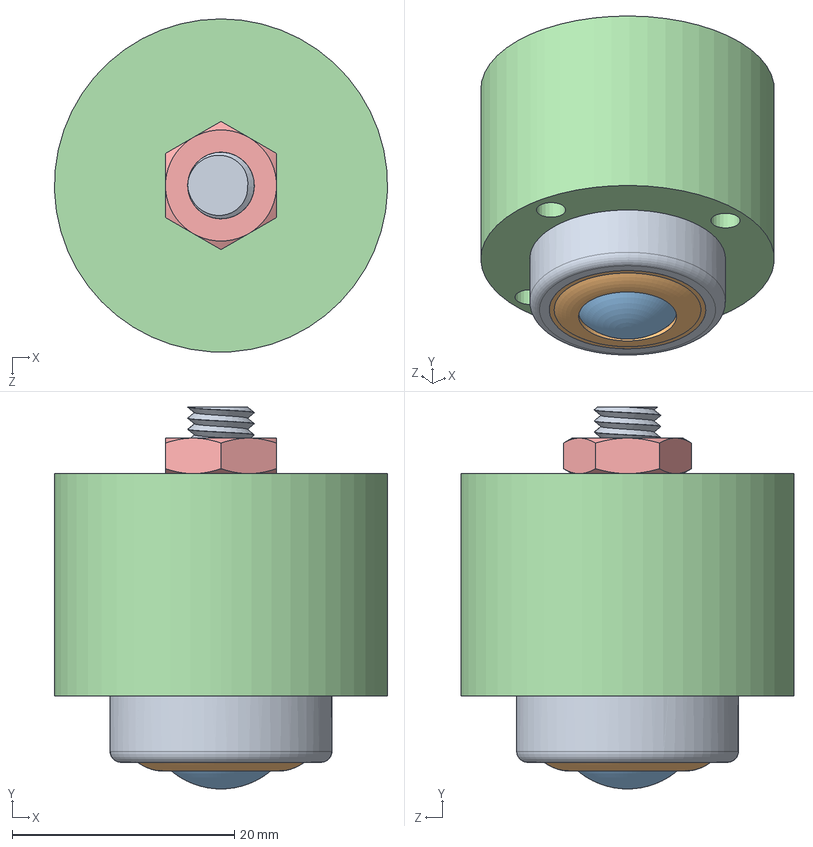
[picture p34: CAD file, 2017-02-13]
SolidWorks/El Padre/Base_roulante/Base du robot/bille_porteuse/bille_porteuse.SLDASM
30.0 x 34.4 x 30.0 mm
contour_roulement
porte_bille
bille
Support_bille_appui
hex thin nut chamfered gradeab_iso

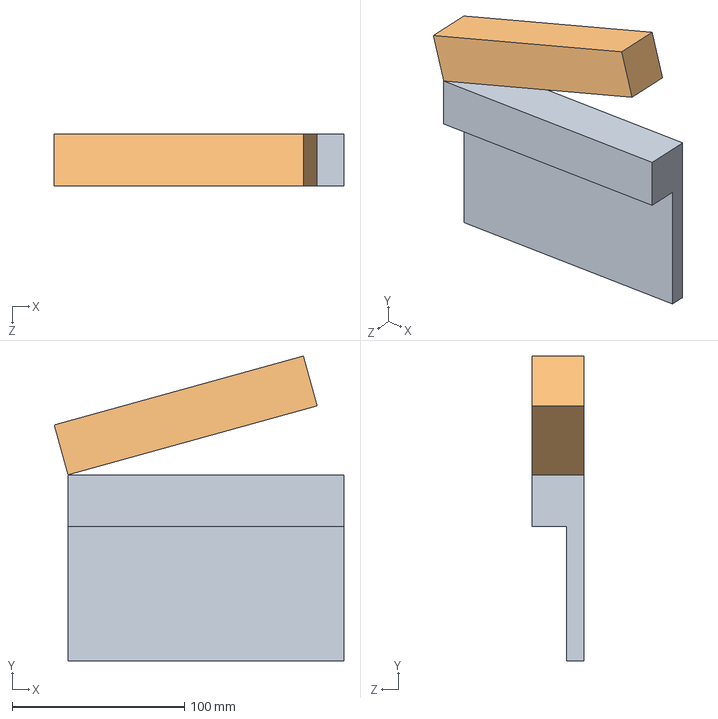
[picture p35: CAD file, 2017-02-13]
SolidWorks/El Padre/Base_roulante/Claps/Clap/AssemblageClaps.SLDASM
168.0 x 176.9 x 30.0 mm
bas claps
haut claps

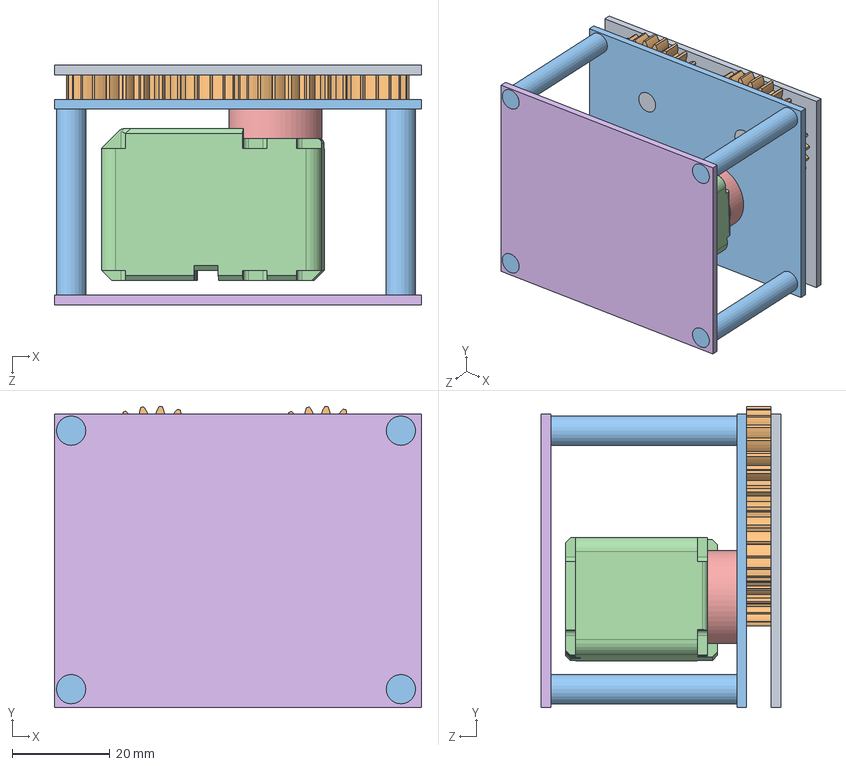
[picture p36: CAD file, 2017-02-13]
SolidWorks/El Padre/Base_roulante/assemblage_spot2/assemblage_pince.SLDASM
75.0 x 61.6 x 49.0 mm
plaque_engrenage_qui_sort
spur gear_iso x 3
plaque_engrenage_avec_trou
herkulex_DRS0101_servomoteur
roulementHerkulex
plaque_pivot_servo

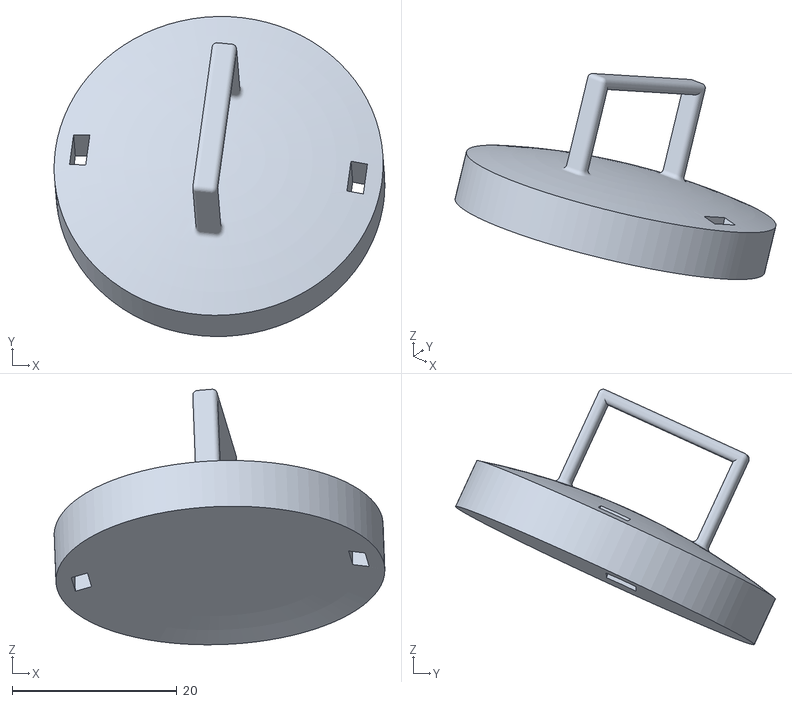
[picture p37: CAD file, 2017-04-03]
SolidWorks/El Padre/Base_roulante/cristeo/Assemblage canon - lanceur-1.STL
40.2 x 38.9 x 31.1

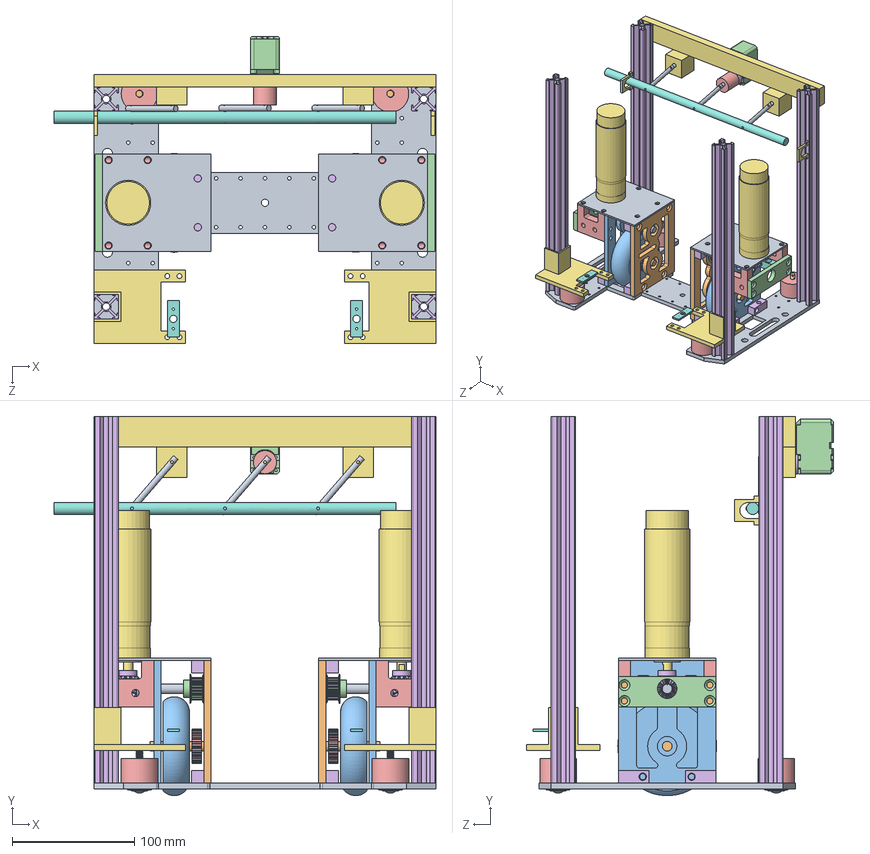
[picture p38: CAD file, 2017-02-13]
SolidWorks/El Padre/Base_roulante/Claps/AntiClapsFinal/Base_grand_robot_AvecAntiClap.SLDASM
312.7 x 310.5 x 251.0 mm
base_v3
contour_roulement x 4
porte_bille x 4
bille x 4
Support_bille_appui x 4
Profile20O6_V2 x 4
fixationServo x 2
adaptateurServo x 2
support moteur x 2
support central x 2
support inter x 2
support exter x 2
RENFORT x 4
fix carre x 6
moteur x 2
support coulisse x 4
axe inter x 2
axe roue x 2
roue x 2
poulie 20 dents x 2
poulie 30 dents x 2
Straight Miter Gear_ISO x 4
support
tige
tigeSupport x 3
Vis 1 x 3
Vis 2 x 3
herkulex_DRS0101_servomoteur
RenfortServomoteur
roulementHerkulex
BloqueurTige x 2

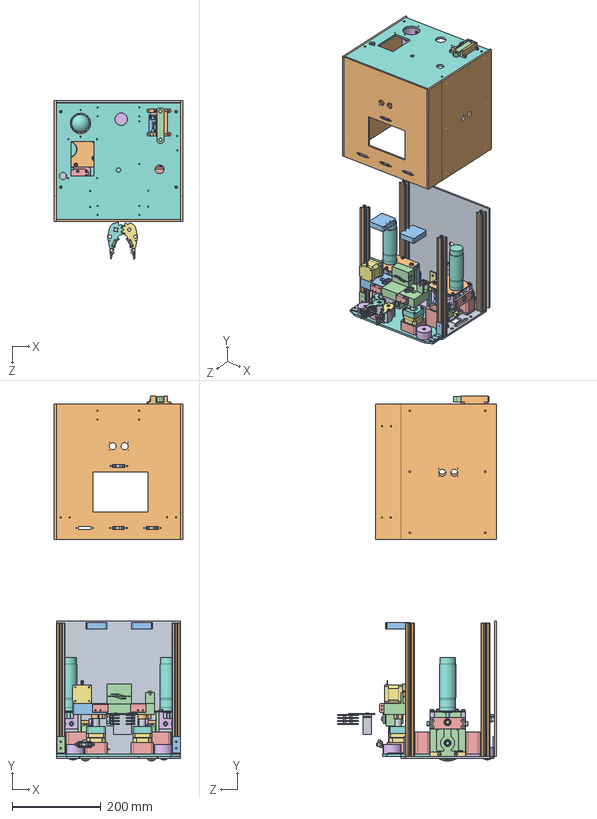
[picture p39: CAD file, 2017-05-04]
SolidWorks/El Padre/Base_roulante/Base du robot/Base_grand_robot_V3.SLDASM
290.0 x 822.2 x 358.1 mm
base_v3
support moteur x 2
support central x 2
support inter x 2
support exter x 2
RENFORT x 4
fix carre x 6
moteur x 2
support coulisse x 4
axe inter x 2
axe roue x 2
roue x 2
angular contact ball bearing_68_iso x 10
poulie 20 dents x 2
poulie 30 dents x 2
socket head cap screw_iso x 20
socket countersunk head screw_iso x 19
Profile x 4
bille x 2
porte_bille x 2
contour_roulement x 2
Support_bille_appui x 2
ecrou socket x 2
support_haut_moteur
Protege_arriere
Protege_laterale_gauche x 2
support-milieu_droite
support-milieu_gauche
poulie pour courroie x 2
roulement lineaire M8-24 x 6
moteur NEMA 17-40mm x 3
support8moteur x 2
Adaptateur x 2
PINCE_ANTI_WOOBLE x 2
support_haut x 2
ENSEMBLE CHARIOT DEPLACEMENT_1
support_fin_de_coursz x 2
socle00
EQUERRE x 8
socleV2
Ram Electronics Shop_IR Sensor_SHARP x 5
PROTEGE FACE
EQUERRE SOCLE DROIT
EQUERRE SOCLE
support batterieV2 x 4
canon
acroche
la boule
lanceur
servo moteur
support servo moteur 1
support moteur 2
piece pince x 8
Pièce2 x 12
Pièce4
Pièce3
Pièce5 x 2
Bas
End-Stop
Tirette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

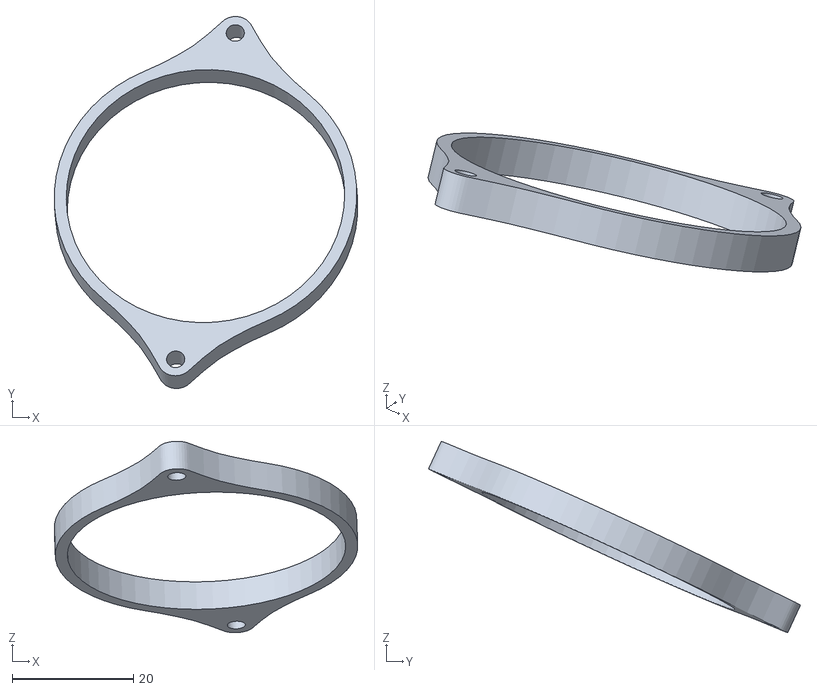
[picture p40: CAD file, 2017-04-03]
SolidWorks/El Padre/Base_roulante/cristeo/Assemblage canon - bague support-1.STL
50.1 x 61.4 x 31.6

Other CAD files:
SolidWorks/El Padre/isen robot 2016-17/Funny Action/fixatio canon.SLDASM
SolidWorks/El Padre/Base_roulante/Claps/AntiClapsFinal/Assembly anti claps 2.SLDASM
SolidWorks/El Padre/Base_roulante/cristeo/Assemblage canon - acroche-1.STL
SolidWorks/El Padre/isen robot 2016-17/SUPPORT DU MILIEU.SLDASM
SolidWorks/El Padre/Base_roulante/Actionneur/herkulex_DRS0101_servomoteur.SLDPRT
SolidWorks/El Padre/Base_roulante/Actionneur/roulementHerkulex.SLDPRT
SolidWorks/El Padre/Base_roulante/Assemblage popcorn/Pièces/Bac/Bac ping pong.SLDPRT
SolidWorks/El Padre/Base_roulante/Assemblage popcorn/Pièces/Clapet/Axe servo.SLDPRT
SolidWorks/El Padre/Base_roulante/Assemblage popcorn/Pièces/Clapet/clapet1.SLDPRT
SolidWorks/El Padre/Base_roulante/Assemblage popcorn/Pièces/Clapet/clapet2.SLDPRT
SolidWorks/El Padre/Base_roulante/Assemblage popcorn/Pièces/Tige/tige.SLDPRT
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

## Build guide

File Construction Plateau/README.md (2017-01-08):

# Construction Plateau

Dossier destiné à accueillir les documents concernant le plateau.

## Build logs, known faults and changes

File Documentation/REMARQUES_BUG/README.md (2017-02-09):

# Remarques

## Encodeurs

La prise femelle de l'encodeur droit accueille la prise male de l'encodeur gauche. <br/>
La prise femelle de l'encodeur gauche accueille la prise male de l'encodeur droit. 

## Moteur

Il ne faut jamais mettre les entrées IN1 et IN2 d'un même moteur à l'état HIGH.

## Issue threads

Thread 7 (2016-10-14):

Coder actionneur ramassage de cylindre

nsobczak, 2016-10-14:
- [x] designer l'actionneur avec solidworks
- [x] 1er code de la pince
- [x] test déplacement de la pince
- [x] création de fonctions pour le déplacement de la pince
- [x] lancer la pince depuis l'écran
- [x] Actionner la pince à partir d'un autre arduino

Closed 2017-04-13.

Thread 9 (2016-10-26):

Ecran - actualiser une valeur en continue

nsobczak, 2016-10-26:
- [x] Créer menus de debug
- [x] Afficher les variables en lecture seule
- [x] Actualiser les variables avec un bouton
- [ ] Actualiser les variables de manière continue
- [ ] Récupérer les valeurs de variables en I2C

Closed 2017-05-02.

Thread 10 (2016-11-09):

Ecran I2C - envoyer un ordre à l'arduino contenant le code de l'asservissement du robot

nsobczak, 2016-11-09:

nsobczak, 2016-11-09:
Il faut :
- ajouter à la bibliothèque I2C une fonction de conversion d'un int sur 2 octets
- écrire fonction d'envoi d'une variable puis de sa valeur sur 2 octets
- écrire fonction de reception d'une variable et de sa valeur sur 2 octets

nsobczak, 2016-11-28:
Problème :
L'esclave ne rentre pas dans la boucle onReceive()

nsobczak, 2016-12-02:
Problème résolu

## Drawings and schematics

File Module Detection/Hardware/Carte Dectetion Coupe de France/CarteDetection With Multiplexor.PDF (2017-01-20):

# Carte de Détéction

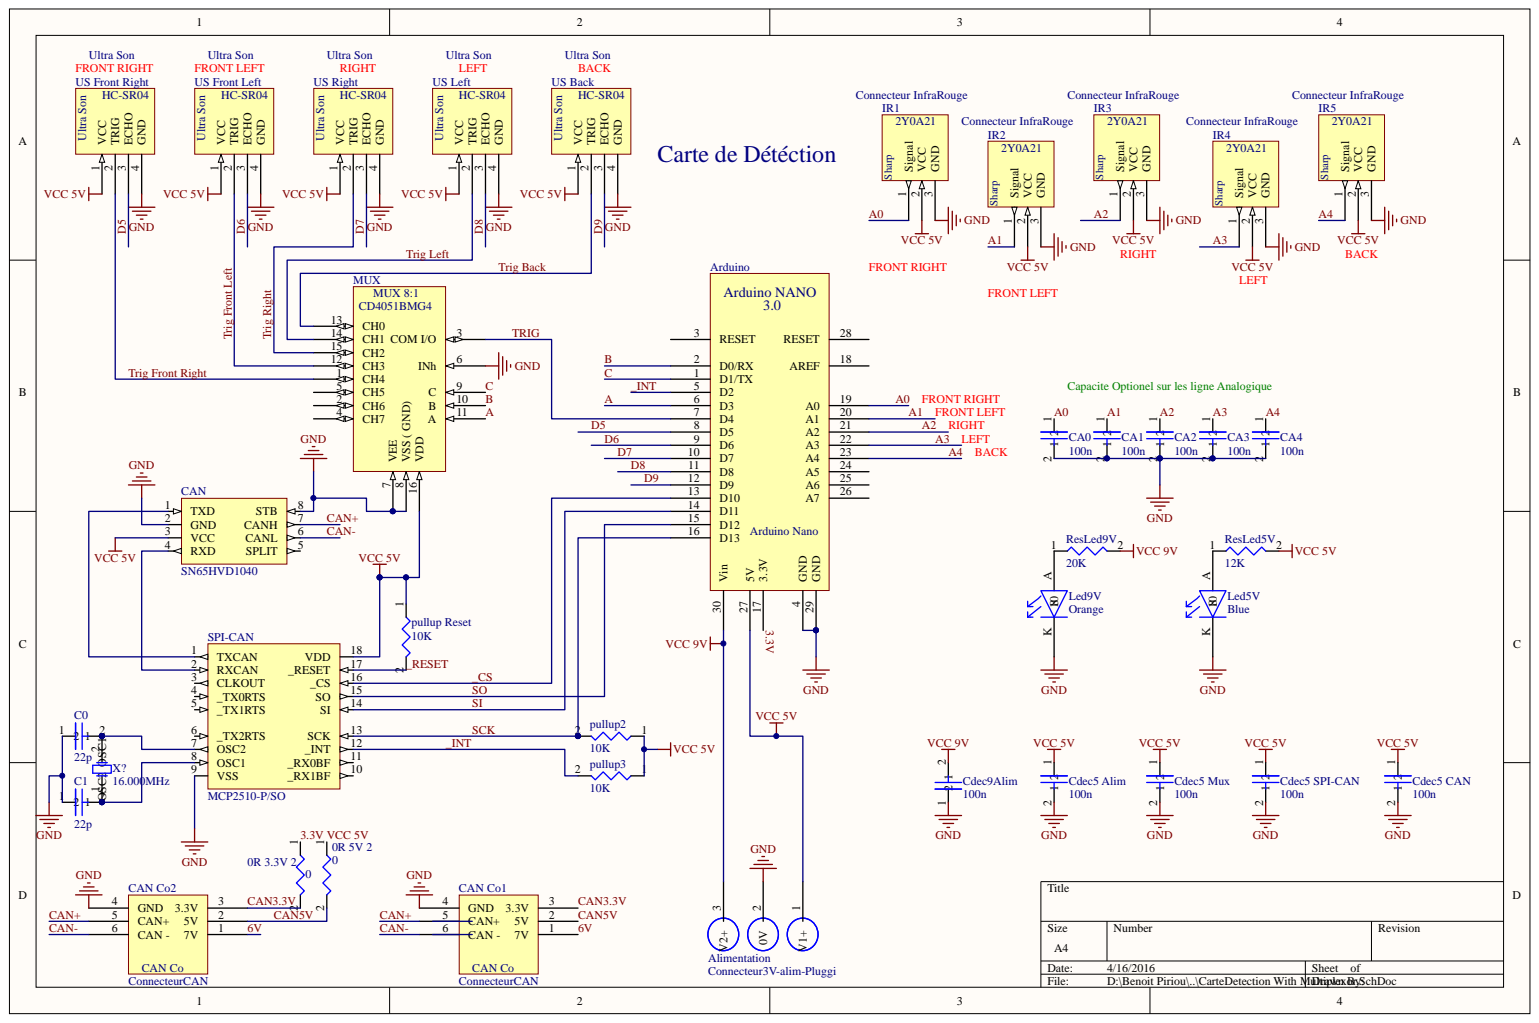
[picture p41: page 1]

Capacite Optionel sur les ligne Analogique

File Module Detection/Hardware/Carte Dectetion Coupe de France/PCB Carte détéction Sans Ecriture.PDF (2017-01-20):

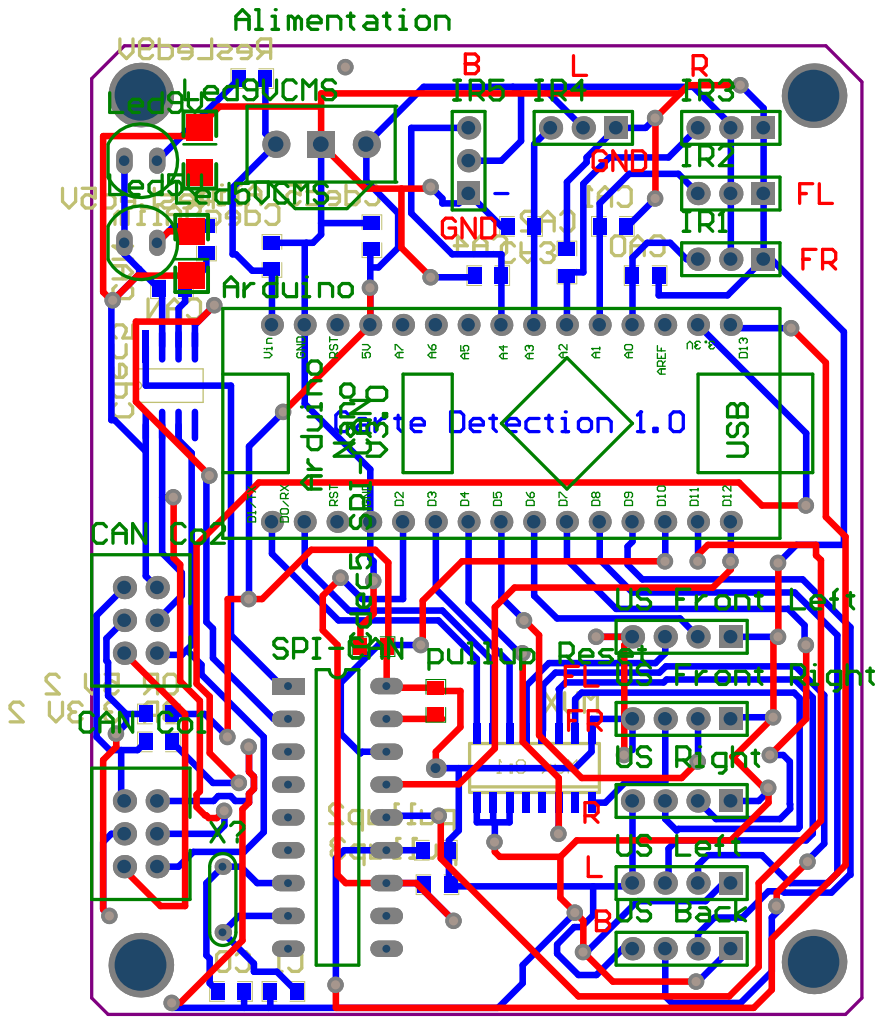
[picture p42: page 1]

Comment | Description | Designator | Footprint | LibRef | Quantity
RES | resistance | 0R 3.3V 2, 0R 5V 2, pullup2, pullup3, pullup Reset, ResLed5V, ResLed9V | 0805 | RES | 7
PIN | | 1, 2, 3, 4, 5, 6, 7, 8, 9, 10, 11, 12, 13, 14, 15, 16 | TESTPOINT | PIN | 16
Connecteur3V-alim-Pluggi | | Alimentation | CONNECTEUR3V-ALIM-PLUGGI | Connecteur3V-alim-Pluggi | 1
Arduino Nano | | Arduino | Arduino Nano FootPrint | Arduino Nano | 1
CAP | capacité non polarisée | C0, C1, CA0, CA1, CA2, CA3, CA4, Cdec5 Alim, Cdec5 CAN, Cdec5 Mux, Cdec5 SPI-CAN, Cdec9Alim | 0805 | CAP | 12
SN65HVD1040 | | CAN | SO8 | SN65HVD1040 | 1
ConnecteurCAN | | CAN Co1, CAN Co2 | CAN Connecteur | ConnecteurCAN | 2
Connecteur InfraRouge | | IR1, IR2, IR3, IR4, IR5 | Connecteur InfraRouge | Connecteur InfraRouge | 5
comment | LED 5mm/3mm/CMS | Led5V, Led9V | LED5 | LED | 2
MCP2510-P/SO | CAN controler | SPI-CAN | DIP18 | MCP2510-P/SO | 1
Ultra Son | | US Back, US Front Left, US Front Right, US Left, US Right | Conecteur UltraSon | Ultra Son | 5
16.000MHz | Quartz | X? | HC5U | XTAL | 1
MUX 8:1 CD4051B | | [NoValue], MUX | MUX 8:1* | MUX 8:1 CD4051B | 2

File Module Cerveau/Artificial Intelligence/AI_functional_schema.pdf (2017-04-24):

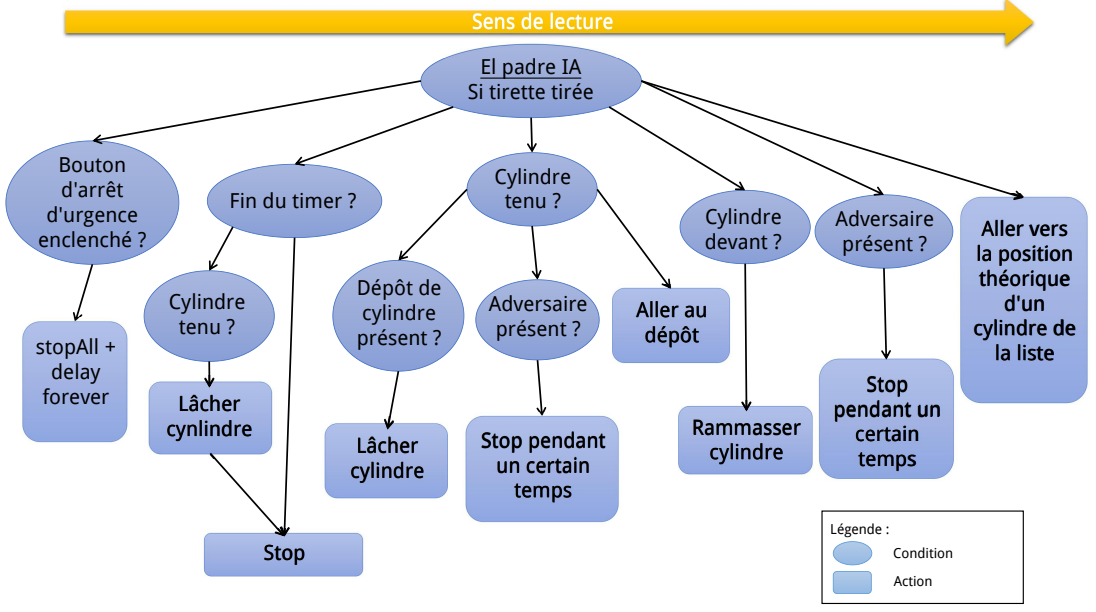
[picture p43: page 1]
Stop; Aller vers la position théorique d'un cylindre de la liste; Cylindre devant ?; Cylindre tenu ?; Lâcher cynlindre; Stop pendant un certain temps; Adversaire présent ?; Rammasser cylindre; Lâcher cylindre; Dépôt de cylindre présent ?; Aller au dépôt; Légende :; Condition; Action; Bouton d'arrêt d'urgence enclenché ?; stopAll + delay forever

Sens de lecture
El padre IA
Si tirette tirée

Fin du timer ?

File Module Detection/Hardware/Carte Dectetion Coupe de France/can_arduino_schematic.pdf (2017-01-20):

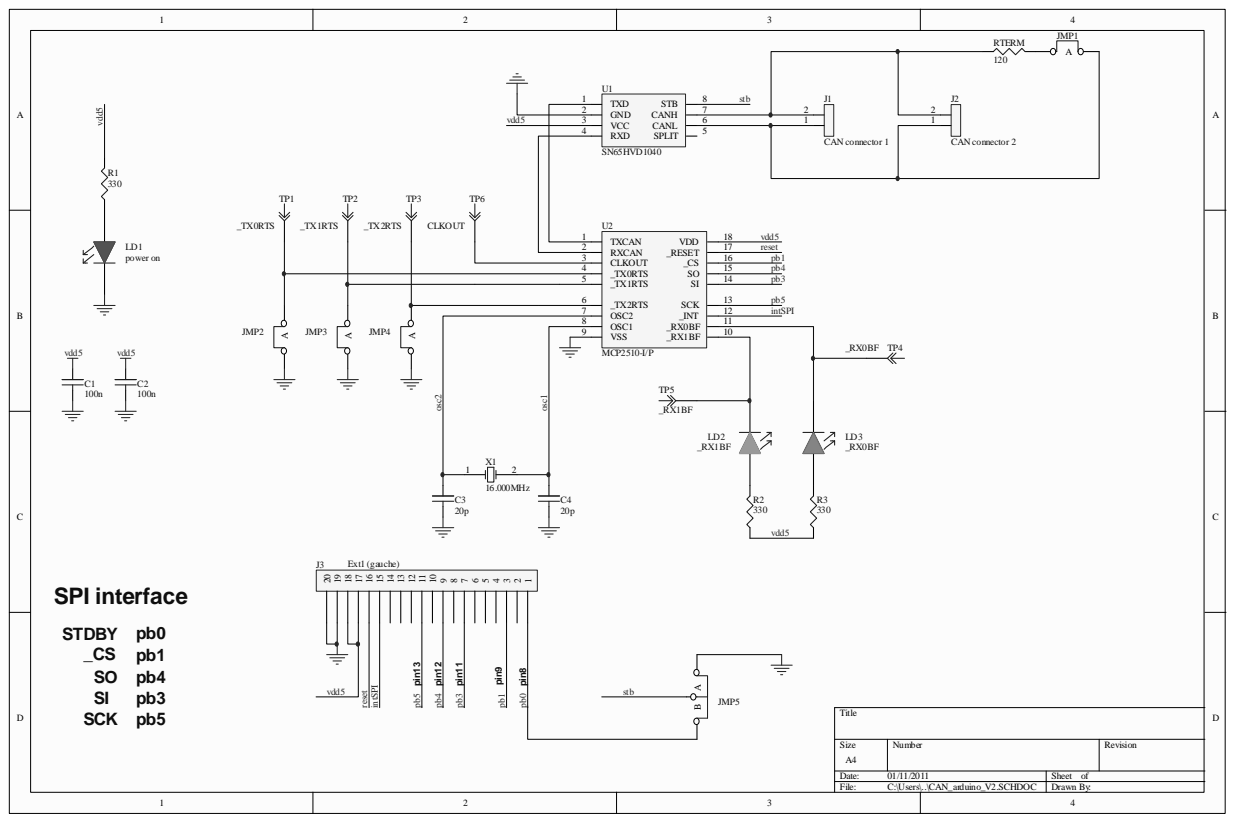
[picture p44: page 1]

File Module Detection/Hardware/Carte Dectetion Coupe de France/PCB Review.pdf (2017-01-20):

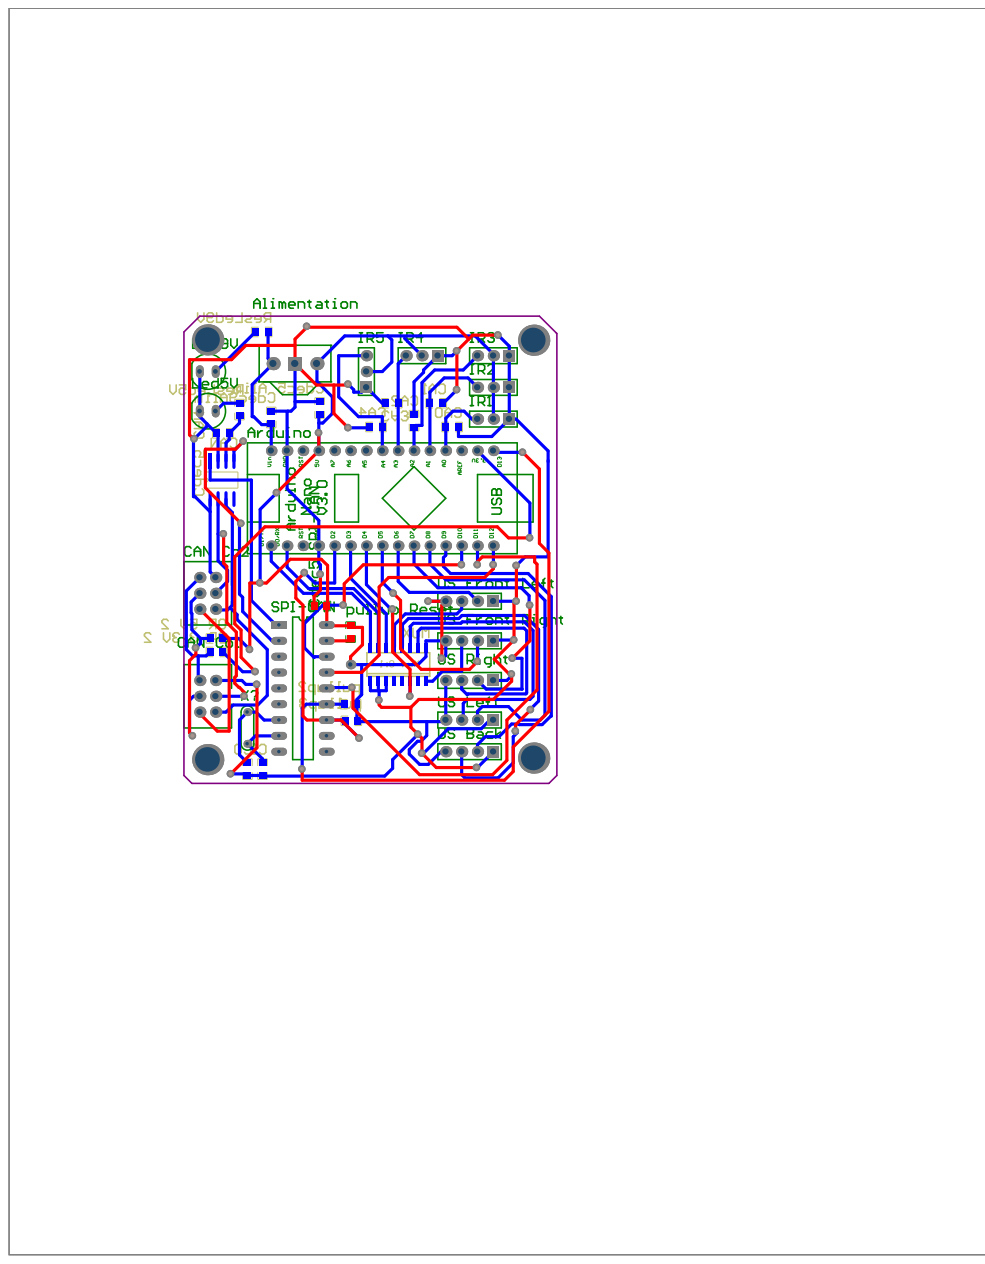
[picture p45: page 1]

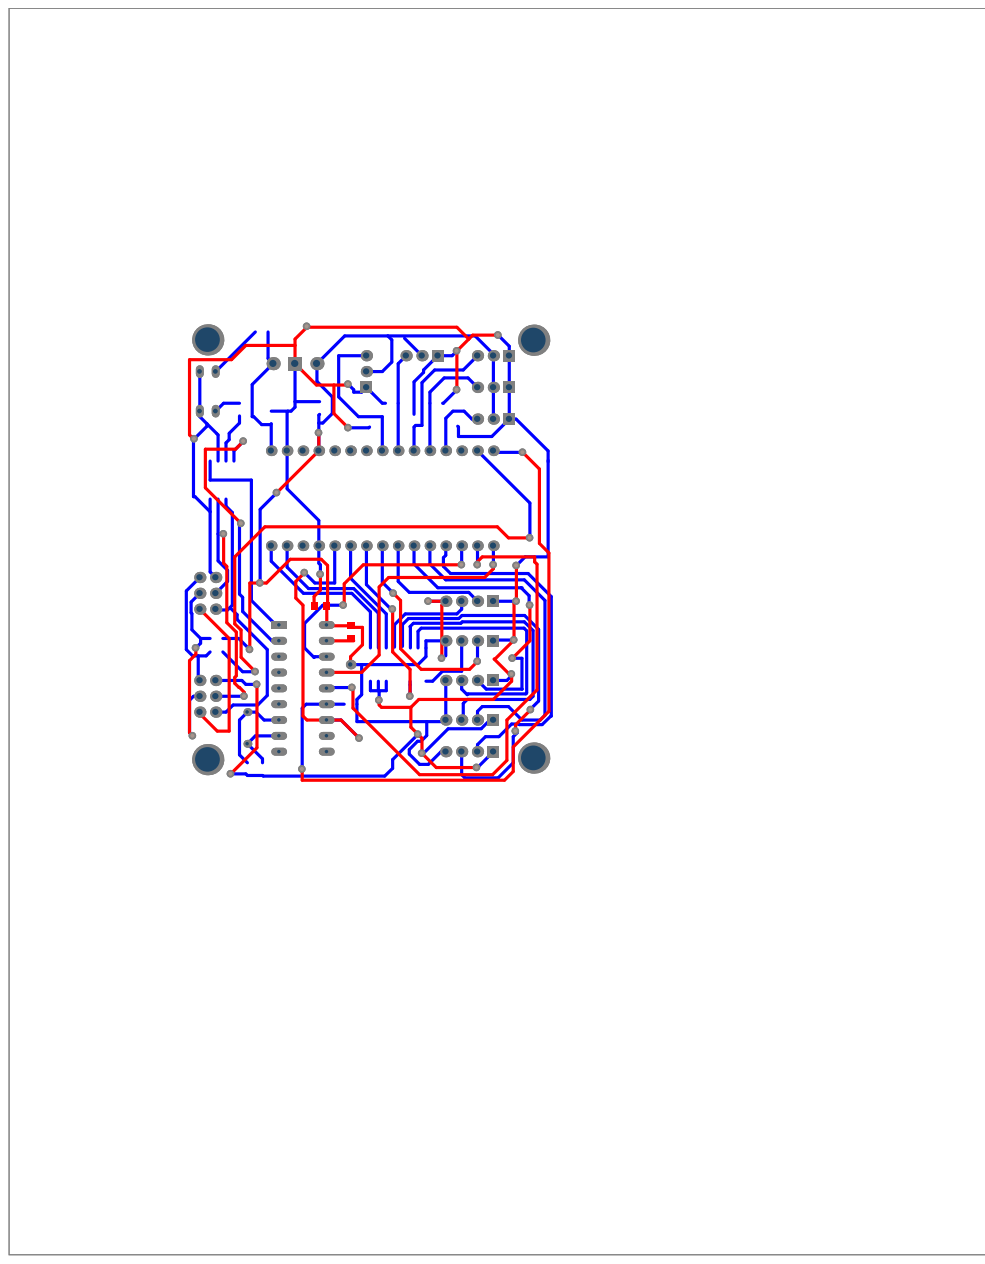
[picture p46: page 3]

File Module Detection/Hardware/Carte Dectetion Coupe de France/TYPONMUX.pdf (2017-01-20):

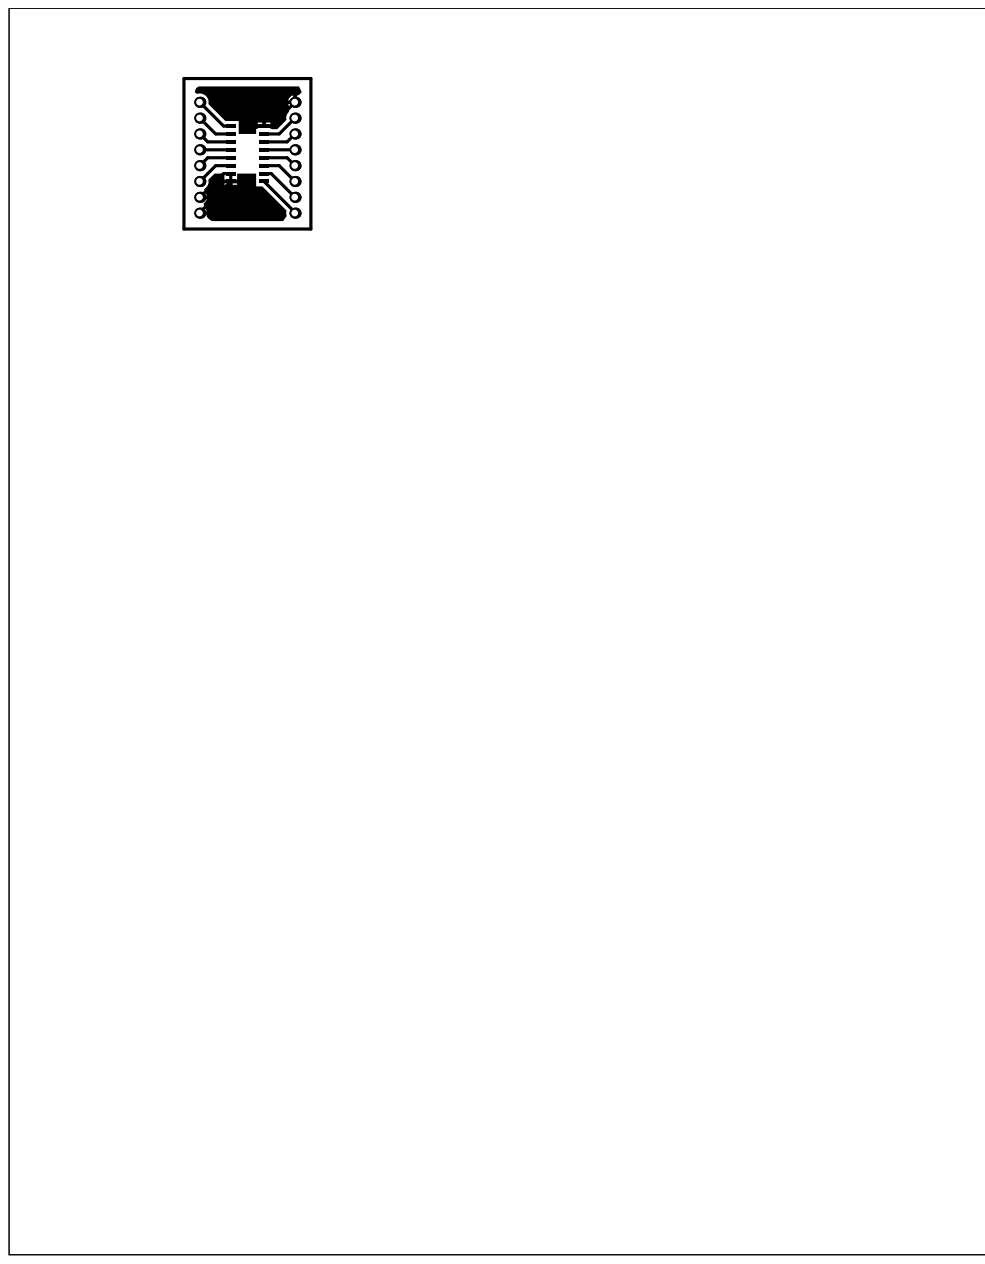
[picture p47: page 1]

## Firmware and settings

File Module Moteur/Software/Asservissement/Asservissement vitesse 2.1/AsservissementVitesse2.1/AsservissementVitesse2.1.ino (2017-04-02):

/**
 *    \file caraterisationVitesseMoteur.ino
 *    \brief test des drivers, test des encodeurs
 *
 *    \author Arthur Duytschaever et Nicolas Sobczak
 *    \date Février 2017
 */
//_______________________________________________________________________________________________________
/* ======================================================================================================
 *      Include
 * ======================================================================================================
 */
#include <Arduino.h>

/* ======================================================================================================
 *      Variables globales
 * ======================================================================================================
 */
#define encoder0PinA_L 13   //encodeur gauche A
#define encoder0PinB_L 12   //encodeur gauche B
#define encoder0PinA_R 11   //encodeur droit A
#define encoder0PinB_R 10   //encodeur droit B

#define MotorR 6 // Attention sur Due PWM ou Pwm sont des keyword -> donc ne pas les utiliser pour des nom de variable
#define MotorL 3
#define IN1MotorR 52
#define IN2MotorR 53
#define IN1MotorL 22
#define IN2MotorL 23

#define diametreRoueCodeuse 0.05228 // 52,28mm
#define nombreTicksPour1TourDeRoue 2500

const float Pi = 3.14159;
const float perimetreRoueCodeuse = diametreRoueCodeuse*Pi;

unsigned int tick_codeuse_R = 0;   // Compteur de tick de la codeuse
unsigned int tick_codeuse_L = 0;   // Compteur de tick de la codeuse

// unsigned long pulseDuration;
// unsigned long totalDuration;
unsigned long testDuration;
unsigned long testStart;
float consigneMoteur = 1;
float sommeErreurGauche = 0;
float sommeErreurDroite = 0;
float erreurPrecedenteGauche = 0;
float erreurPrecedenteDroite = 0;
float consignePWMR;
float consignePWML;
float kpGauche = 0;
float kiGauche = 0;
float kdGauche = 0;
float kpDroit = 1;
float kiDroit = 0;
float kdDroit = 0;


/* ======================================================================================================
 *      Fonctions
 * ======================================================================================================
 */
/**
 * \fn void setup()
 * \brief fonction setup d'arduino
 */
void setup()
{
        Serial.begin(115200);     // Initialisation port COM
        pinMode(MotorR,OUTPUT);
        pinMode(MotorL,OUTPUT);
        pinMode(IN1MotorR,OUTPUT);
        pinMode(IN2MotorR,OUTPUT);
        pinMode(IN1MotorL,OUTPUT);
        pinMode(IN2MotorL,OUTPUT);

        pinMode(encoder0PinA_L, INPUT);
        pinMode(encoder0PinB_L, INPUT);
        pinMode(encoder0PinA_R, INPUT);
        pinMode(encoder0PinB_R, INPUT);

        attachInterrupt(encoder0PinA_R, compteur_tick_R, CHANGE);    // Interruption sur tick de la codeuse (interruption 0 = pin2 arduino mega)
       
        attachInterrupt(encoder0PinA_L, compteur_tick_L, CHANGE);    // Interruption sur tick de la codeuse (interruption 0 = pin2 arduino mega)

        /*
           === Remarques ===
           Pour changer le pwm: 0 -> 255
           100% = 0
           75% = 63
           50% = 127
           25% = 191
           0% = 255
         */
        //Moteur droit
        analogWrite(MotorL,255);
        analogWrite(MotorR,255);
        digitalWrite(IN1MotorR, LOW);
        digitalWrite(IN2MotorR, LOW);
        digitalWrite(IN1MotorL, LOW);
        digitalWrite(IN2MotorL, LOW);
        analogWrite(MotorL,255);
        analogWrite(MotorR,255);

        consignePWML = calculConsignePWMMotorL(consigneMoteur);
        consignePWMR = calculConsignePWMMotorR(consigneMoteur);
        testDuration = millis();
        testStart = millis();
        
}


/**
 * \fn void loop()
 * \brief fonction loop d'arduino
 */
void loop()
{
        
        //fréquence de mesure de 50Hz
        if (millis() - testDuration >= 20) {
                //Attente de 5" avant le début
                if ((millis() - testStart > 5000) && (millis() - testStart < 15000)) {

                        //Moteur droit
                        //double vitesseReelGauche = calculVitesse(tick_codeuse_L, millis() - testDuration);
                        double vitesseReelDroite = calculVitesse(tick_codeuse_R, millis() - testDuration);
                        float erreurDroite = consigneMoteur - vitesseReelDroite;
                        //float erreurGauche = consigneMoteur - vitesseReelGauche;
                        //sommeErreurGauche += erreurGauche;
                        sommeErreurDroite += erreurDroite;
                        //float deltaErreurGauche = erreurGauche - erreurPrecedenteGauche;
                        float deltaErreurDroite = erreurDroite - erreurPrecedenteDroite;
                        //erreurPrecedenteGauche = erreurGauche;
                        erreurPrecedenteDroite = erreurDroite;

                        int cmdMoteurDroit = kpDroit*erreurDroite+kiDroit*sommeErreurDroite+kdDroit*deltaErreurDroite + consignePWMR;
                        //int cmdMoteurGauche = kpGauche*erreurGauche+kiGauche*sommeErreurGauche+kdGauche*deltaErreurGauche + consignePWML;
                        if(cmdMoteurDroit<0){
                          cmdMoteurDroit = 0;
                        }
                        else if(cmdMoteurDroit>255){
                          cmdMoteurDroit = 255;
                        }

                        /*if(cmdMoteurGauche<0){
                          cmdMoteurGauche =0;
                        }
                        else if(cmdMoteurGauche>255){
                          cmdMoteurGauche = 255;
                        }*/
                        
                        digitalWrite(IN1MotorR, LOW);
                        digitalWrite(IN2MotorR, HIGH);
                        digitalWrite(IN1MotorL, LOW);
                        digitalWrite(IN2MotorL, LOW);
                        analogWrite(MotorL,255);
                        analogWrite(MotorR,cmdMoteurDroit);
                        //Serial.print("\t testDuration : \t " );
                        Serial.println(millis() - testDuration);
                        // //Serial.print("\t tick_codeuse_L : \t");
                        // Serial.println(tick_codeuse_L);
                        // // Serial.print("\t testDuration : \t");
                         //Serial.println(testDuration);
                        // ne pas oublier de change l'encoder L ou R
                        //Serial.print("\t consignePWM : \t " );
                        //Serial.println(consignePWM);
                        //Serial.print("\t calculVitesse : \t " );
                        printDouble(calculVitesse(tick_codeuse_R, millis() - testDuration), 1000000);
                        //printDouble(calculVitesse(tick_codeuse_L, millis() - testDuration), 1000000);                         
                }
                else if (millis() > 15000) {
                        endTest();
                }
                testDuration = millis();
                // Decommenter pour le moteur droit
                tick_codeuse_R = 0;
                //tick_codeuse_L = 0;
        }
}


/**
 * \fn void compteur_tick_R()
 * \brief Interruption sur tick de la codeuse right
 */
void compteur_tick_R()
{
        tick_codeuse_R++; // On incrémente le nombre de tick de la codeuse
}


/**
 * \fn void compteur_tick_L()
 * \brief Interruption sur tick de la codeuse left
 */
void compteur_tick_L()
{
        tick_codeuse_L++; // On incrémente le nombre de tick de la codeuse
}


/**
 * \fn calculVitesse
 * \param unsigned int tick_codeuse, unsigned long duration
 * \brief calcule la vitesse instantannée
 * \return unsigned long vitesse
 */
double calculVitesse(unsigned int tick_codeuse, unsigned long duration)
{
        double nombre_tours = (double) tick_codeuse / (double) nombreTicksPour1TourDeRoue;
        double tour_par_seconde = ((double)nombre_tours/(double)duration)*1000;

        return (double)perimetreRoueCodeuse * tour_par_seconde;
}
/**
 * \fn calculConsignePWM(double y)
 * \brief fonction contenant l'équation permettant de convertir la consigne vitesse en consigne PWM
 * \param double y, y > 1,5056
 * \return x
 */
float calculConsignePWMMotorR(float consigne_vitesse_moteur)
{
        if(consigne_vitesse_moteur < 0) consigne_vitesse_moteur = 0.0;
        else if(consigne_vitesse_moteur > 1.421) consigne_vitesse_moteur = 1.421;
        //y = -73.928 * x² - 35.964 * x + 204.14; = -60,778x2 - 62,861x + 212,94
        return -73.928 * consigne_vitesse_moteur*consigne_vitesse_moteur - 35.964 * consigne_vitesse_moteur + 204.14;// sqrt(1.0/(-0.00002) * (consigne_vitesse_moteur - 1.5056) ) - 65.0;
}
float calculConsignePWMMotorL(float consigne_vitesse_moteur)
{
        if(consigne_vitesse_moteur < 0) consigne_vitesse_moteur = 0.0;
        else if(consigne_vitesse_moteur > 1.421) consigne_vitesse_moteur = 1.421;
        //y = -73.928 * x² - 35.964 * x + 204.14; = -60,778x2 - 62,861x + 212,94
        return -60.778 * consigne_vitesse_moteur*consigne_vitesse_moteur - 62.861 * consigne_vitesse_moteur + 212.94;// sqrt(1.0/(-0.00002) * (consigne_vitesse_moteur - 1.5056) ) - 65.0;
}

void printDouble( double val, unsigned int precision){
// prints val with number of decimal places determine by precision
// NOTE: precision is 1 followed by the number of zeros for the desired number of decimial places
// example: printDouble( 3.1415, 100); // prints 3.14 (two decimal places)

        Serial.print (int(val)); //prints the int part
        Serial.print("."); // print the decimal point
        unsigned int frac;
        if(val >= 0)
                frac = (val - int(val)) * precision;
        else
                frac = (int(val)- val ) * precision;
        int frac1 = frac;
        while( frac1 /= 10 )
                precision /= 10;
        precision /= 10;
        while(  precision /= 10)
                Serial.print("0");

        Serial.println(frac,DEC);
}


void endTest()
{
        analogWrite(MotorL,255);
        analogWrite(MotorR,255);
        digitalWrite(IN1MotorR, LOW);
        digitalWrite(IN2MotorR, LOW);
        digitalWrite(IN1MotorL, LOW);
        digitalWrite(IN2MotorL, LOW);
        analogWrite(MotorL,255);
        analogWrite(MotorR,255);
}


/**
 * \fn void testDriver()
 * \brief fonction qui teste qui les drivers fonctionnent correctement
 */
void testDriver()
{
        //Moteur gauche
        analogWrite(MotorL,255);
        analogWrite(MotorR,255);
        Serial.print("On moteuL gauche \t 1");
        digitalWrite(IN1MotorR, LOW);
        digitalWrite(IN2MotorR, LOW);
        digitalWrite(IN1MotorL, HIGH);
        digitalWrite(IN2MotorL, LOW);
        Serial.print("\t 2");
        analogWrite(MotorL,100);
        analogWrite(MotorR,255);
        Serial.print("\t 3");
        delay(3000);
        Serial.println("\t 4");

        //Moteur droit
        analogWrite(MotorL,255);
        analogWrite(MotorR,255);
        Serial.print("On moteuL droit \t 1");
        digitalWrite(IN1MotorR, HIGH);
        digitalWrite(IN2MotorR, LOW);
        digitalWrite(IN1MotorL, LOW);
        digitalWrite(IN2MotorL, LOW);
        Serial.print("\t 2");
        analogWrite(MotorL,255);
        analogWrite(MotorR,100);
        Serial.print("\t 3");
        delay(3000);
        Serial.println("\t 4");

        //2 moteurs
        analogWrite(MotorL,255);
        analogWrite(MotorR,255);
        Serial.print("On 2 moteurs \t 1");
        digitalWrite(IN1MotorR, HIGH);
        digitalWrite(IN2MotorR, LOW);
        digitalWrite(IN1MotorL, HIGH);
        digitalWrite(IN2MotorL, LOW);
        Serial.print("\t 2");
        analogWrite(MotorL,100);
        analogWrite(MotorR,100);
        Serial.print("\t 3");
        delay(3000);
        Serial.println("\t 4");


        //Moteur droit
        analogWrite(MotorL,255);
        analogWrite(MotorR,255);
        Serial.print("On moteuL droit \t 1");
        digitalWrite(IN1MotorR, HIGH);
        digitalWrite(IN2MotorR, LOW);
        digitalWrite(IN1MotorL, LOW);
        digitalWrite(IN2MotorL, LOW);
        Serial.print("\t 2");
        analogWrite(MotorL,255);
        analogWrite(MotorR,100);
        Serial.print("\t 3");
        delay(3000);
        Serial.println("\t 4");

        //Moteur gauche
        analogWrite(MotorL,255);
        analogWrite(MotorR,255);
        Serial.print("On moteuL gauche \t 1");
        digitalWrite(IN1MotorR, LOW);
        digitalWrite(IN2MotorR, LOW);
        digitalWrite(IN1MotorL, HIGH);
        digitalWrite(IN2MotorL, LOW);
        Serial.print("\t 2");
        analogWrite(MotorL,100);
        analogWrite(MotorR,255);
        Serial.print("\t 3");
        delay(3000);
        Serial.println("\t 4");

        //2 moteurs
        analogWrite(MotorL,255);
        analogWrite(MotorR,255);
        Serial.print("On 2 moteurs \t 1");
        digitalWrite(IN1MotorR, HIGH);
        digitalWrite(IN2MotorR, LOW);
        digitalWrite(IN1MotorL, HIGH);
        digitalWrite(IN2MotorL, LOW);
        Serial.print("\t 2");
        analogWrite(MotorL,100);
        analogWrite(MotorR,100);
        Serial.print("\t 3");
        delay(3000);
        Serial.println("\t 4");
}

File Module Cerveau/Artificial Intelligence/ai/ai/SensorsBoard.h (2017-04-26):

/**
 *    \file SensorsBoard.h
 *    \brief classe carte capteurs
 *
 *    \author Nicolas SOBCZAK
 *    \date Mars 2017
 */
//_______________________________________________________________________________________________________
/* ======================================================================================================
 *      Include
 * ======================================================================================================
 */
#include "Arduino.h"
#include <Wire.h>
#include "i2cCommunication.h"

#define _DEBUG_SENSORSBOARD_ false

#define _SENSORSBOARD_RECEIVEADRESS_ 11

#define _NUMBER_OF_SENSORS_ 9 // 5 ir + 4 us

//TODO: changer les define pour les remplacer par la bonne disance
#define _CYLINDER_DISTANCE_ 14.0 //voir la pince
#define _DISTANCE_WHERE_CYLINDER_IS_READY_TO_BE_CAUGHT_ 8.0 //voir la distance pince-cylindre
#define _BASE_DISTANCE_ 8.5 //3cm
#define _FOE_DISTANCE_ 10.0 //10cm par rapport au capteur

/*Notes: tableau id i2c
   {sharpBT, sharpFT, sharpFBR, sharpFBC, sharpFBL};
   {echoPinR, echoPinL, echoPinB1, echoPinB2}

   0 => infraredSensorBackValue;
   1 => infraredSensorFrontTopValue;
   2 => infraredSensorFrontBottomRightValue;
   3 => infraredSensorFrontBottomCenterValue;
   4 => infraredSensorFrontBottomLeftValue;

   5 => ultrasonicRightValue;
   6 => ultrasonicLeftValue;
   7 => ultrasonicBack1Value;
   8 => ultrasonicBack2Value;
 */

/* ======================================================================================================
 *      Class
 * ======================================================================================================
 */
class SensorsBoard
{
private:

static int infraredSensorFrontBottomRightValue;
static int infraredSensorFrontBottomLeftValue;
static int infraredSensorFrontBottomCenterValue;
static int infraredSensorFrontTopValue;
static int infraredSensorBackValue;

static int ultrasonicFrontValue;
static int ultrasonicRightValue;
static int ultrasonicLeftValue;
static int ultrasonicBackValue;

//____________________
public:

SensorsBoard();

static int getInfraredSensorFrontBottomRightValue();
static int getInfraredSensorFrontBottomLeftValue();
static int getInfraredSensorFrontBottomCenterValue();
static int getInfraredSensorFrontTopValue();
static int getInfraredSensorBackValue();

static int getUltrasonicFrontValue();
static int getUltrasonicRightValue();
static int getUltrasonicLeftValue();
static int getUltrasonicBackValue();

static void setInfraredSensorFrontBottomRightValue(int infraredSensorFrontBottomRightValue);
static void setInfraredSensorFrontBottomLeftValue(int infraredSensorFrontBottomLeftValue);
static void setInfraredSensorFrontBottomCenterValue(int infraredSensorFrontBottomCenterValue);
static void setInfraredSensorFrontTopValue(int infraredSensorFrontTopValue);
static void setInfraredSensorBackValue(int infraredSensorBackValue);

static void setUltrasonicFrontValue(int ultrasonicFrontValue);
static void setUltrasonicRightValue(int ultrasonicRightValue);
static void setUltrasonicLeftValue(int ultrasonicLeftValue);
static void setUltrasonicBackValue(int ultrasonicBackValue);


void receive3bytes();
void updateAllSensorsValue();

bool checkForCylinderOnSensorFrontBottomLeft();
bool checkForCylinderOnSensorFrontBottomCenter();
bool checkForCylinderOnSensorFrontBottomRight();
bool checkForCylinder();

bool checkForBaseOnSensorFrontBottomLeft();
bool checkForBaseOnSensorFrontBottomCenter();
bool checkForBaseOnSensorFrontBottomRight();
bool checkForBase();

bool checkForHindranceOnFront();
bool checkForHindranceOnRight();
bool checkForHindranceOnLeft();
bool checkForHindranceOnBack();
bool checkForHindrance();




};

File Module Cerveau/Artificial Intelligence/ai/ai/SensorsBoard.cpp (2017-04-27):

/**
 *    \file SensorsBoard.cpp
 *    \brief classe carte capteurs
 *
 *    \author Nicolas SOBCZAK
 *    \date Mars 2017
 */
//_______________________________________________________________________________________________________
/* ======================================================================================================
 *      Initialisation
 * ======================================================================================================
 */
#include "SensorsBoard.h"

int SensorsBoard::infraredSensorFrontBottomRightValue = 0;
int SensorsBoard::infraredSensorFrontBottomLeftValue = 0;
int SensorsBoard::infraredSensorFrontBottomCenterValue = 0;
int SensorsBoard::infraredSensorFrontTopValue = 0;
int SensorsBoard::infraredSensorBackValue = 0;
int SensorsBoard::ultrasonicFrontValue = 0;
int SensorsBoard::ultrasonicRightValue = 0;
int SensorsBoard::ultrasonicLeftValue = 0;
int SensorsBoard::ultrasonicBackValue = 0;


/* ======================================================================================================
 *      Constructor, getter, setter
 * ======================================================================================================
 */
SensorsBoard::SensorsBoard()
{
}

int SensorsBoard::getInfraredSensorFrontBottomRightValue()
{
        return infraredSensorFrontBottomRightValue;
}

int SensorsBoard::getInfraredSensorFrontBottomLeftValue()
{
        return infraredSensorFrontBottomLeftValue;
}

int SensorsBoard::getInfraredSensorFrontBottomCenterValue()
{
        return infraredSensorFrontBottomCenterValue;
}

int SensorsBoard::getInfraredSensorFrontTopValue()
{
        return infraredSensorFrontTopValue;
}

int SensorsBoard::getInfraredSensorBackValue()
{
        return infraredSensorBackValue;
}

int SensorsBoard::getUltrasonicFrontValue()
{
        return ultrasonicFrontValue;
}

int SensorsBoard::getUltrasonicRightValue()
{
        return ultrasonicRightValue;
}

int SensorsBoard::getUltrasonicLeftValue()
{
        return ultrasonicLeftValue;
}

int SensorsBoard::getUltrasonicBackValue()
{
        return ultrasonicBackValue;
}


void SensorsBoard::setInfraredSensorFrontBottomRightValue(int infraredSensorFrontBottomRightValue)
{
        SensorsBoard::infraredSensorFrontBottomRightValue = infraredSensorFrontBottomRightValue;
}

void SensorsBoard::setInfraredSensorFrontBottomLeftValue(int infraredSensorFrontBottomLeftValue)
{
        SensorsBoard::infraredSensorFrontBottomLeftValue = infraredSensorFrontBottomLeftValue;
}

void SensorsBoard::setInfraredSensorFrontBottomCenterValue(int infraredSensorFrontBottomCenterValue)
{
        SensorsBoard::infraredSensorFrontBottomCenterValue = infraredSensorFrontBottomCenterValue;
}

void SensorsBoard::setInfraredSensorFrontTopValue(int infraredSensorFrontTopValue)
{
        SensorsBoard::infraredSensorFrontTopValue = infraredSensorFrontTopValue;
}

void SensorsBoard::setInfraredSensorBackValue(int infraredSensorBackValue)
{
        SensorsBoard::infraredSensorBackValue = infraredSensorBackValue;
}

void SensorsBoard::setUltrasonicFrontValue(int ultrasonicFrontValue)
{
        SensorsBoard::ultrasonicFrontValue = ultrasonicFrontValue;
}

void SensorsBoard::setUltrasonicRightValue(int ultrasonicRightValue)
{
        SensorsBoard::ultrasonicRightValue = ultrasonicRightValue;
}

void SensorsBoard::setUltrasonicLeftValue(int ultrasonicLeftValue)
{
        SensorsBoard::ultrasonicLeftValue = ultrasonicLeftValue;
}

void SensorsBoard::setUltrasonicBackValue(int ultrasonicBackValue)
{
        SensorsBoard::ultrasonicBackValue = ultrasonicBackValue;
}


/* ======================================================================================================
 *      Methods
 * ======================================================================================================
 */

/**
 * \fn void receiveEvent(int howMany - fonction qui est exécutée lorsque des données sont envoyées par le Maître. Cette fonction est enregistrée comme un événement ("event" en anglais), voir la fonction setup()
 * \param int howMany
 */
void SensorsBoard::receive3bytes()
{
        if (_DEBUG_SENSORSBOARD_) {Serial.print("Wire.available(): "); Serial.println(Wire.available()); }
        if (Wire.available() == 3)
        {
                //lecture de la variable
                byte var = Wire.read();
                //lecture des 2 octets suivants
                byte x = Wire.read();
                byte y = Wire.read();
                //reconstitution de la valeur
                byte bytesTab[2] = {x, y};
                int value = recoverIntFrom2Bytes(bytesTab);

                switch ( var )  // cf. les références des variables en haut du fichier
                {
                case 0:
                        if (_DEBUG_SENSORSBOARD_) Serial.println("variable recue : InfraredSensorBack");
                        this->setInfraredSensorBackValue(value);
                        break;
                case 1:
                        if (_DEBUG_SENSORSBOARD_) Serial.println("variable recue : InfraredSensorFrontTop");
                        this->setInfraredSensorFrontTopValue(value);
                        break;
                case 2:
                        if (_DEBUG_SENSORSBOARD_) Serial.println("variable recue : InfraredSensorFrontBottomRight");
                        this->setInfraredSensorFrontBottomRightValue(value);
                        break;
                case 3:
                        if (_DEBUG_SENSORSBOARD_) Serial.println("variable recue : InfraredSensorFrontBottomCenter");
                        this->setInfraredSensorFrontBottomCenterValue(value);
                        break;
                case 4:
                        if (_DEBUG_SENSORSBOARD_) Serial.println("variable recue : InfraredSensorFrontBottomLeft");
                        this->setInfraredSensorFrontBottomLeftValue(value);
                        break;
                case 5:
                        if (_DEBUG_SENSORSBOARD_) Serial.println("variable recue : UltrasonicRight");
                        this->setUltrasonicRightValue(value);
                        break;
                case 6:
                        if (_DEBUG_SENSORSBOARD_) Serial.println("variable recue : UltrasonicLeft");
                        this->setUltrasonicLeftValue(value);
                        break;
                case 7:
                        if (_DEBUG_SENSORSBOARD_) Serial.println("variable recue : UltrasonicFront (back1)");
                        this->setUltrasonicFrontValue(value);
                        break;
                case 8:
                        if (_DEBUG_SENSORSBOARD_) Serial.println("variable recue : UltrasonicBack (back2)");
                        this->setUltrasonicBackValue(value);
                        break;
                default:
                        if (_DEBUG_SENSORSBOARD_) Serial.println("variable recue inconnue");
                }
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

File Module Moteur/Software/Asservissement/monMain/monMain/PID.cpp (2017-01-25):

/**
 *    \file PID.cpp
 *    \brief Code du correcteur Proportionnel Intégrateur Dérivateur (PID) du grand Robot. Permet de corriger la consigne de sortie en fonction de la consigne d'entrée (éviter les oscilations de position et d'angle)
 *
 *Codé pour "Spark core"  www.spark.io
 *
 *Par : Thibaut LOCQUET
 *      Octobre 2012
 *Modification: Clément LETELLIER
 *              Mars 2014
 *Modification: Nicolas SOBCZAK
 *              Octobre 2016
 */
//_______________________________________________________________________________________________________


/* ======================================================================================================
 *      Include
 * ======================================================================================================
 */
#include "structures.h"
#include "odometrie.h"
#include "PID.h"


/* ======================================================================================================
 *      Fonctions de la classe PID
 * ======================================================================================================
 */
/**
 * \fn PID  
 * \brief constructeur qui initialise le PID
 * \param double kP, double kI, double kD coeff du PID utilise pour calculer le PWM
 * \param double periode ???
 */
PID::PID(double kP, double kI, double kD, double periode)
{

    //init coeff
    m_kP = kP;
    m_kI = kI;
    m_kD = kD;

    //init values
    m_sumError = 0;
    m_lastError = 0;
    m_diffError = 0;

    m_periode = periode;
}


/**
 * \fn PID  
 * \brief constructeur sans paramètres qui initialise le PID
 */
PID::PID()
{
}


//_______________________________________________________________________________________________________
/**
 * \fn PID  
 * \brief fonction qui reset le PID
 * \param double error reset le PID avec la derreniere error
 */
void PID::resetPID(double error)
{
    m_lastError = error;
    m_sumError = 0;
    m_diffError = 0;
}


//_______________________________________________________________________________________________________
/**
 * \fn PID  
 * \brief fonction qui calcule le PID 
 * \param double error utiliser pour avoir l'erreur l'actuel 
 * \return retourne la valeur de PID calculée
 */
double PID::computePID(double error)
{

    double P, I, D;
    double PID;

    m_sumError = m_sumError + error;

    //calcule la variation d'erreur
    m_diffError = error - m_lastError;

    //remplace dernière erreur
    m_lastError = error;


    //Propotionnel
    P = error * m_kP;

    //Intégrateur
    I = m_sumError * m_kI;// * m_periode;

    //Dérivateur
    D = (m_diffError * m_kD);// m_periode ;

    PID = P + I + D;

    /*Serial.print ("error :\t");
    Serial.println (error);
    Serial.print ("m_diffError :\t");
    Serial.println (m_diffError);
    Serial.print ("m_sumError :\t");
    Serial.println ( m_sumError);
    Serial.print ("P :\t");
    Serial.println (P);
    Serial.print ("I :\t");
    Serial.println (I);
    Serial.print ("D :\t");
    Serial.println (D);
    */
    return PID;
}

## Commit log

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2016-10-19 Resolution du probleme de l'ecran d'accueil qui revenait tout le temps
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2016-12-05 Add missing files + Add I2C test07
    [BotMenu.ino, i2cCommunication.cpp, slave_1.ino]
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2016-12-15 Ajout de la partie Hardware
    [BMI_HEARDER_4mm.PcbLib, BMI_HEARDER_4mm.SchLib, Commande_composant.xlsx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]
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2016-12-18 Creation du shield pour la carte Cerveau
    [Connector2_3.5mm_puissance.PcbLib, Connector2_3.5mm_puissance.SchLib, LvlConverter_Adg3304.PcbLib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]
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2016-12-19 Update README.md
    Correction nom de dossier
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2016-12-19 Suppression de bibliothèques non utilisées
    [Configuration.h, Configuration_adv.h, Menu Plans.xlsx]
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2016-12-21 Ajout d'un bouton reset correction du mapping des encoder
    [LvlConverter_Adg3304.PcbLib, ShieldArduino Due.~(5).SchDoc, Shield_Arduino_Due.PCBDOC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]
2016-12-30 V 1.1 shield a verifier avec les composant
    [ShieldArduino Due.~(5).SchDoc, Shield_Arduino_Due.PCBDOC, Shield_arduino_Due.PrjPCB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]
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2017-01-08 Mise a jour des connecteur Creation librairy pour les connecteur cosse
    [Connector_Cosse.PcbLib, Connector_Cosse.SchLib]
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2017-01-12 mise a jour des connecteur
    [Connector2_3.5mm_puissance.PcbLib, Connector2_3.5mm_puissance.SchLib, Connector_Cosse.PcbLib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]
2017-01-12 ajout des connecteurs, des plan de masse , et des capa de decouplage
    [Carte_alim.PCBDOC, Carte_alim.PcbLib, Carte_alim.SchDoc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]
2017-01-12 Remise de la carte shield moteur dans le bon dossier
    [Connector2_3.5mm_puissance.PcbLib, Connector2_3.5mm_puissance.SchLib, Connector_Cosse.PcbLib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]
2017-01-15 Mise a jour des plan de masse Mise a jour des commentaire sur la carte preparation a la fabrication
    [Carte_alim.GBL, Carte_alim.GBO, Carte_alim.GBP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]
2017-01-17 Preparation a la fabrication
    [Shield_arduino_Due.PrjPCB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]
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2017-01-19 Correction branchement Lvl convert
    [LvlConverter_Adg3304.PcbLib, LvlConverter_Adg3304.SchLib, ShieldArduino Due.~(5).SchDoc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]
2017-01-20 Ajout du module Dectetion : Ajout de la carte de Dectetion de pluggi
    [Arduino Nano Version 3.1.PcbLib, Arduino Nano.SchLib, CarteDetection With Multiplexor.SchDoc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]
2017-01-20 Changement de nom du dossier
    [Carte_alim.GBL, Carte_alim.GBO, Carte_alim.GBP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]
2017-01-20 remplacement du dossier alimentation
    [Carte_alim.GBL, Carte_alim.GBO, Carte_alim.GBP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]
2017-01-20 Creation de la carte capteur
    [Arduino Nano Version 3.1.PcbLib, Arduino Nano.SchLib, CarteDetection With Multiplexor.SchDoc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]
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2017-01-25 Ajout readme dans module detection Majuscule à tous les noms de dossier
    [BMI_HEARDER_4mm.PcbLib, BMI_HEARDER_4mm.SchLib, Commande_composant.xlsx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]
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2017-02-01 Asservissement vitesse: asservissement croisé, moyenne des codeuses Ajout d'un début de tableur pour effectuer la courbe du PID
    [Courbe_PID.xlsx]
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2017-02-04 Mise a jour de la carte detection de pluggi pour utilisation sur notre robot
    [CarteDetection With Multiplexor.SchDoc, CarteDétéction.PrjPCB, PCB Carte détéction Sans Ecriture.PCBDOC]
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2017-02-07 Ajout des connecteur et changement de pin pour les voie A,B,C
    [CarteDetection With Multiplexor.SchDoc, CarteDétéction.PrjPCB, PCB Carte détéction Sans Ecriture.PCBDOC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]
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2017-02-07 Asservissement: modif du Datareader
    [DriverMoteur2.1.PCBDOC, Shield_Arduino_Due.PCBDOC, tableau.csv]
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2017-02-08 Asservissement: Mercredi matin avec nicolas relevé des 1ère mesures => résultats abérrants => réécriture des fonctions
    [tableau.csv, tableau_accélération.csv, tableau_accélération_01.xlsx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]
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2017-02-09 ajout de readme + renommage dossier carte detection
    [Arduino Nano Version 3.1.PcbLib, Arduino Nano.SchLib, CarteDetection With Multiplexor.SchDoc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]
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2017-02-10 Asservissement: traçage courbe + calcul de la vitesse du moteur vendredi matin avec Nicolas
    [tableau.csv, tableau_accélération.csv, tableau_accélération_01.xlsx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]
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2017-02-10 Asservissement: caractérisation vitesse pwm moteur - tableaux de Nicolas
    [tableau.csv, tableau_pwm_255.xls, tableau_pwm_motorL_0.xls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]
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2017-02-14 Prototype avec correction des capteurs fin de course
    [Moteur_deplacement.ino]
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2017-03-01 Asservissment moteur: caractérisation vitesse - timer corrigé - resolution problème de cast - ajout de la fonction printDouble
    [CaracterisationVitessePWM.ino]
2017-03-02 Ajout des courbes pour la caraterisation du moteur
    [tableau.csv, tableau_vitesse_instantannée-temps_moteur_R_0.xlsx, tableau_vitesse_instantannée-temps_moteur_R_127.csv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]
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2017-03-08 Asservissment: PWM correction du code
    [CaracterisationVitessePWM.ino]
2017-03-08 Asservissement: maj code de correction de l'asservissement
    [asservissementVitesse.ino]
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2017-03-17 Creation code test asservissement vitesse mise a jour carte mere
    [CaracterisationMoteur.xlsx, ConvertisseurDeNiveau.SchLib, ShematicShieldCerveau.SchDoc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]
2017-03-21 Mise a jour du code et tableaux d'asservissement en vitesse
    [CaracterisationMoteur.xlsx]
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2017-03-25 Cerveau: - Ajout de la story de l'IA - Réorganisation ShieldCerveau
    [Connector_Cosse.PcbLib, Connector_Cosse.SchLib, ConvertisseurDeNiveau.SchLib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]
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2017-03-27 Ajout de l'initialisation du code de l'AI + Création dossier design
    [BarLed.PCBDOC, BarLed.PrjPcb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]
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2017-04-02 Mise a jour Dossier asservissement , BarLed, ReadArduino et ShieldCerveaux
    [BarLed.PCBDOC, BarLed.PrjPcb, ConvertisseurDeNiveau.SchLib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]
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2017-04-03 Mise à jour solidworks / intégration pince, funny action et capteurs
    [Assemblage canon - acroche-1.STL, Assemblage canon - bague support-1.STL, Assemblage canon - canon-1.STL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]
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2017-04-07 Mise à jour solidworks + ajout de la tirette
    [Assemblagepince.SLDASM, Bas.SLDPRT, CACHE.SLDPRT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]
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2017-04-14 Funny action : ajout arret d'urgence sur le pcb
    [M1.SLDPRT, M2.SLDPRT, M3.SLDPRT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]
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2017-04-17 Funny action : correction pcb
    [Shield_nano.PCBDOC, Shield_nano.SchDoc]
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2017-04-20 Asservissement mise a jour mathlab Mise a jour pin ecran
    [CaracterisationMoteur.xlsx, PCB_Project.PrjPcb, ReponsePIDMethodeCalculatoire.xlsx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]
2017-04-20 Asservissement : mise jour commande, correction de l'erreur precedente
    [Asservissement_vitesse_2.5.ino]
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2017-04-22 Suppression du putain de dossier bar de led
    [PCB_Project.PrjPcb]
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2017-04-24 Funny action : correction angle
    [funny_action.ino]
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
